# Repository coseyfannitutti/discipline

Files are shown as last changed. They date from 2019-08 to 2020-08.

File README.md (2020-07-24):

# DISCIPLINE V2

**65% keyboard assembled with only through hole components, including usb type-c**

**[LICENSE](LICENSE)**

Discipline V2 is licensed under the [Creative Commons Attribution-NonCommercial 4.0 International License](https://creativecommons.org/licenses/by-nc/4.0/). 

This PCB design may be freely reproduced, modified, and manufactured for **PERSONAL USE ONLY** and may not be reproduced in physical form for public sale outside of [CFTKB.com](https://www.cftkb.com). 

If you have built upon this work and have changed the design in a significant way, the non-commercial clause can be waived. If you have developed your own design using files in this repository and would like to sell it, please contact me at bryan@cftkb.com. I fully support those looking to make new things and be creative and will more than likely approve and support your project.

**[BOM, Build Guide, and Flashing Information](./doc)**

**Kits available at [cftkb.com](https://www.cftkb.com)**

**[Optional High Profile Lasercut Acrylic Case](./acrylic-case)**

discipline
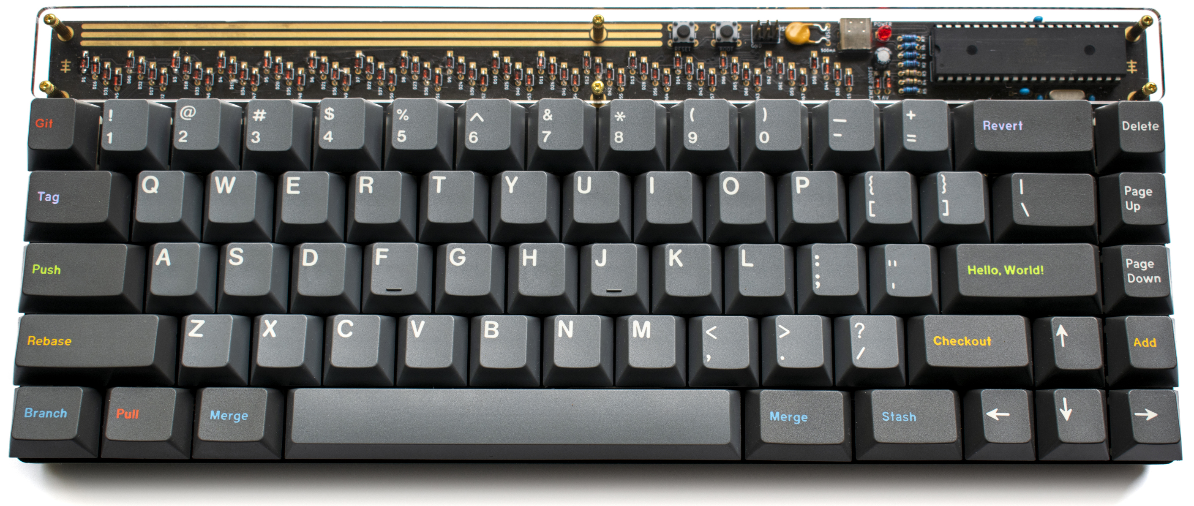
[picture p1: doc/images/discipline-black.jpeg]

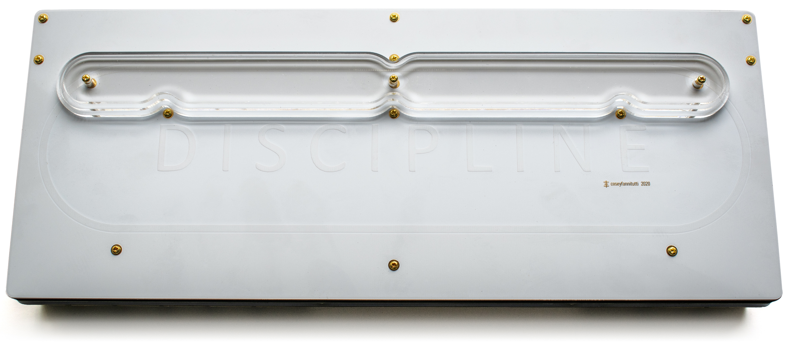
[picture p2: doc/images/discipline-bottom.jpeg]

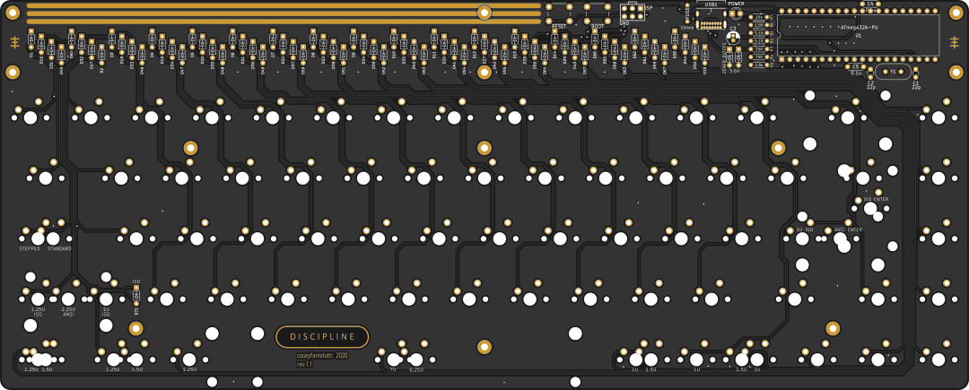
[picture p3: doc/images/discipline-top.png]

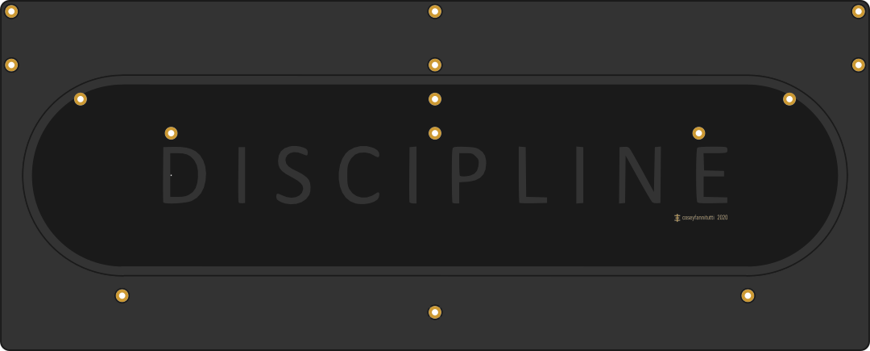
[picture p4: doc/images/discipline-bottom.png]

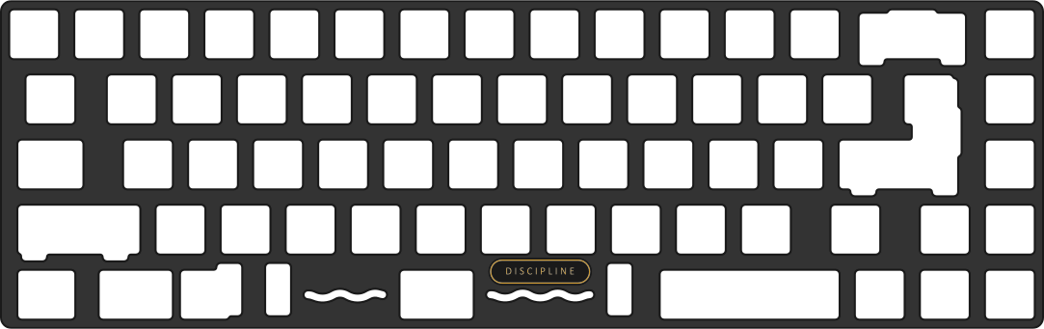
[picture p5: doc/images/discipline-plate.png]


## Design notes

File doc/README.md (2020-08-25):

# DISCIPLINE

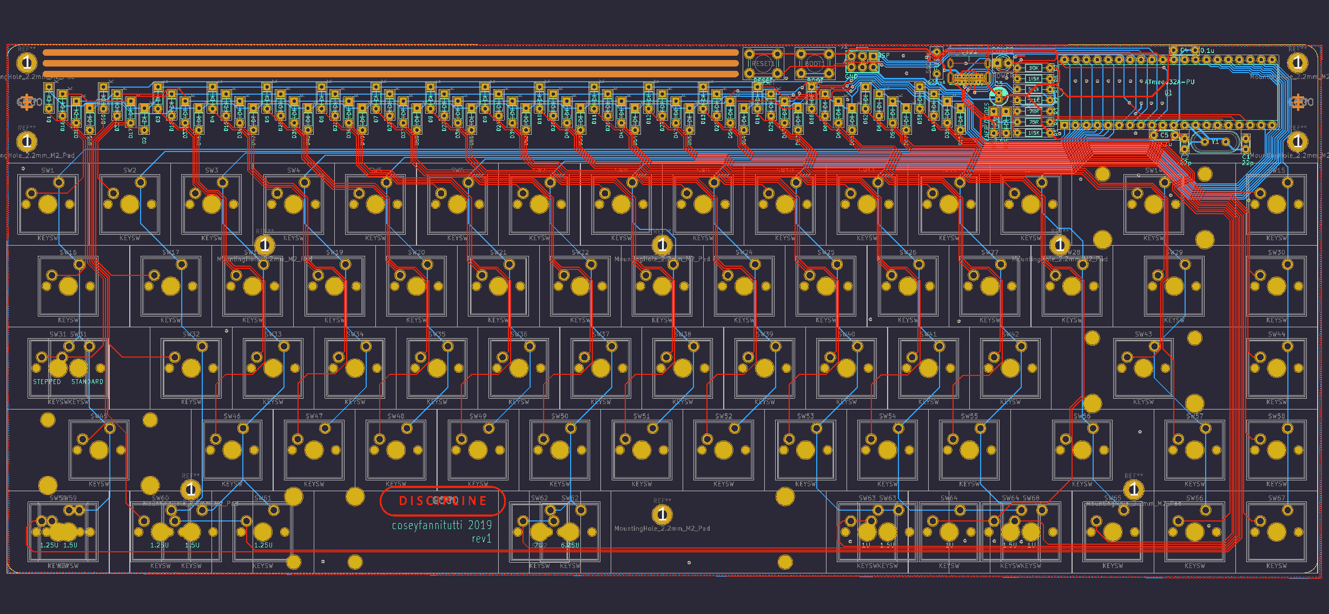
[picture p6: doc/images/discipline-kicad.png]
discipline


[Build Guide](https://www.cftkb.com/s/DISCIPLINE-BUILD-GUIDE.pdf)

[VIA Configurator Guide (Easiest)](https://static1.squarespace.com/static/5c533d33348cd92b886e544d/t/5e9fd1d198a4166c9ccc5b68/1587532241535/DISCIPLINE+VIA+GUIDE.pdf)

[QMK Toolbox Flashing Guide (not needed if using VIA)](https://static1.squarespace.com/static/5c533d33348cd92b886e544d/t/5e9fd3311e3c4e5bc9f8eb21/1587532594225/DISCIPLINE+FLASHING+GUIDE.pdf)

[Command Line Flashing Guide (Advanced)](https://static1.squarespace.com/static/5c533d33348cd92b886e544d/t/5e9fd3567e131c476b0a4f7e/1587532631133/DISCIPLINE+FLASHING+GUIDE+-+COMMAND+LINE.pdf)

[Bootloader](./bootloader)

[BOM (Parts List)](https://octopart.com/bom-tool/W4rybyut)

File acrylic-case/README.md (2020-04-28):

# Lasercut Acrylic Case with POM Plate

***This is case is OPTIONAL and not required. The kit has everything you need for a fully functional keyboard.
This case uses a different plate and is NOT compatible with the plate included in the kit.
If you have already soldered switches, you will need to desolder them and swap the plate.***

***I recommend using [Ponoko](https://www.ponoko.com) to cut the pieces. They have all of the correct/required thicknesses and materials in stock and have the best pricing that I have found for multiple one-off parts. Use clear acrylic for the full range of thickness options and Delrin (POM) for the plate. For proper fit please ensure you use the correct dimensions and material thicknesses noted below. Other colors may be used, but of the colors may have limited thickness options, so you may have to narrow material results by thickness to see which colors are available for that size.***

***Ponoko's automatic size detection when uploading is not flawless, so be sure to manually enter the dimensions below.***

## Part Dimensions/Thickness (Top to Bottom)
1. discipline-top-1.dxf - 320.9 x 138.8 mm - ***2mm thickness CLEAR ACRYLIC***
2. discipline-top-2.dxf ***x2 needed*** - 320.9 x 138.8 mm - ***3mm***
3. discipline-plate.dxf - 320.9 x 138.8 mm - ***1.5mm thickness DELRIN(POM)*** Can be black or white.
4. discipline-open-layer.dxf - 320.9 x 138.8 mm - ***4.5mm thickness***
5. discipline-closed-layer.dxf - 320.9 x 138.8 mm - ***3mm thickness***
6. discipline-bottom.dxf - 320.9 x 138.8 - ***3mm thickness*** Use matte (frosted) or colored acrylic if you don't want to clean up the flux on the bottom of your PCB.
7. discipline-foot-1.dxf - 276.5 x 28mm - ***3mm thickness***
8. discipline-foot-2.dxf - 272.5 x 24mm - ***3mm thickness***
9. discipline-foot-3.dxf - 268.5 x 20mm - ***3mm thickness***

## Screws and Standoffs
1. [30x m2x5mm screws](https://www.aliexpress.com/item/32870342767.html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,searchweb201602_7,searchweb201603_53)
2. [12x m2x14mm standoffs](https://www.aliexpress.com/item/32968906213.html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,searchweb201602_7,searchweb201603_53)
3. [3x m2x5mm standoffs](https://www.aliexpress.com/item/32968906213.html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,searchweb201602_7,searchweb201603_53)

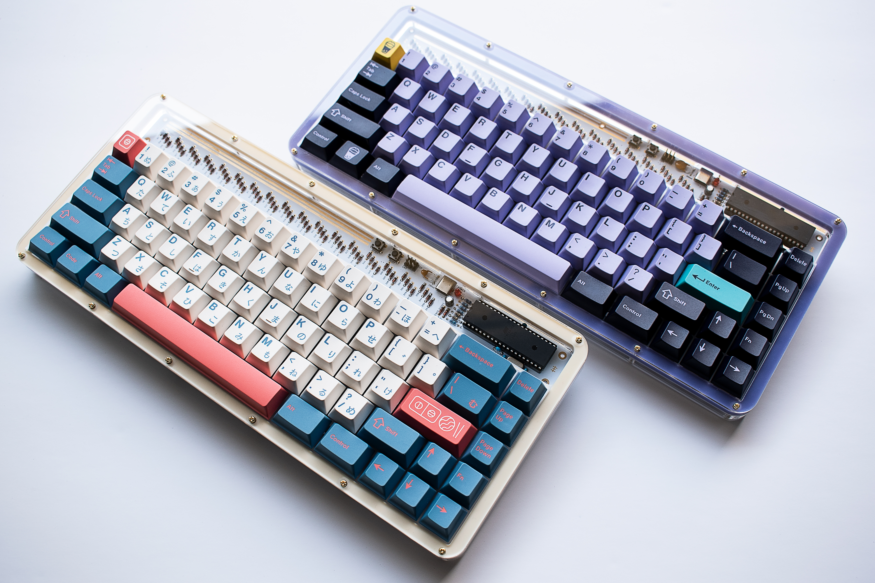
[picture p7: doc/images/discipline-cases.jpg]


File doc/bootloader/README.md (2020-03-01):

# Bootloader

## If you buy a kit from cftkb.com your microcontroller already has the bootloader flashed and you do not need this.

This project uses USBaspLoader as the usb bootloader on the atmega32a.
- My custom bootloader:   
https://github.com/coseyfannitutti/USBaspLoader/tree/atmega32a
  - Please ensure you are in the atmega32a branch of my fork of the USBaspLoader repository when downloading.
  - Follow the directions in the readme for directions on setting up the build environment for your operating system as well as flash instructions.
  - Makefile.inc sets flashing device as usbtiny, as I use a sparkfun pocket avr programmer. If you need to use another programmer please edit line 41 of Makefile.inc accordingly. Only edit Makefile.inc, and NEVER directly edit the actual Makefile.
  - Commands for flashing once build environment is set up:
  
	```make flash``` (flashes makefile)
  
  	```make fuse``` (sets fuses for microcontroller)
  
## Enter bootloader mode
1. Press and hold ```BOOT``` switch
2. Tap ```RESET``` switch
3. Release ```BOOT``` switch

Alternatively, you can hold ```BOOT``` switch while inserting the USB cable.

If you have successfully entered bootloader mode you should see USBaspLoader in device manager or as a connected device in QMK Toolbox.

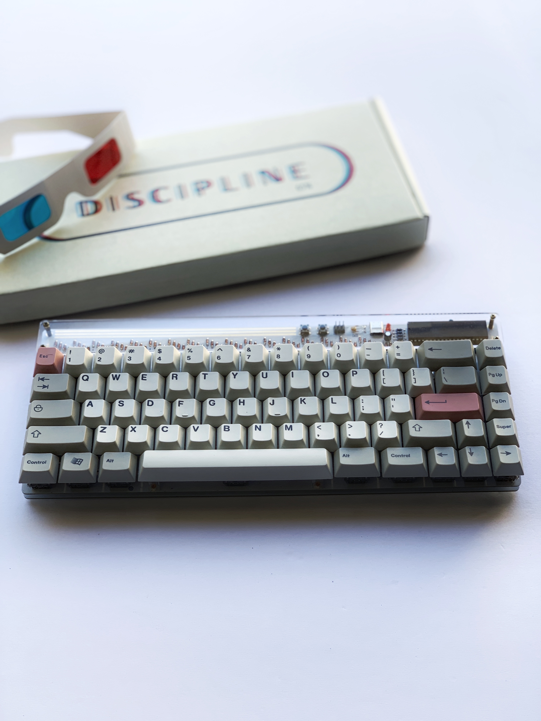
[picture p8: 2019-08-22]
doc/images/discipline-productpage.jpeg

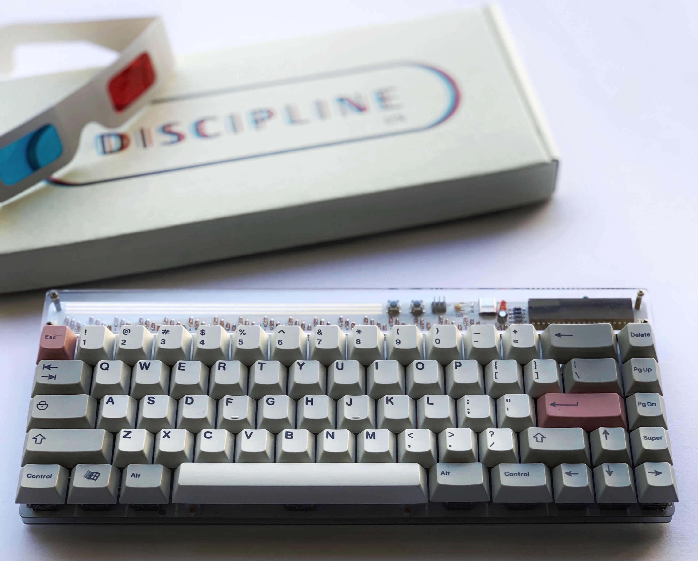
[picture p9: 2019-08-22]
doc/images/discipline-productpage-crop.jpeg

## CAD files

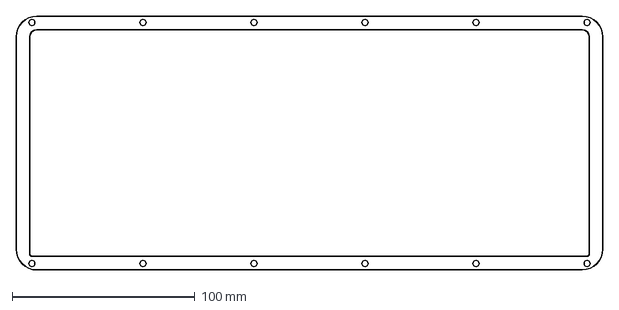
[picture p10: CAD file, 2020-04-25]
acrylic-case/discipline-top2.dxf
320.9 x 138.8 mm

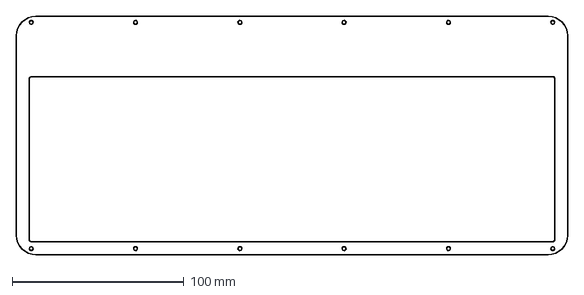
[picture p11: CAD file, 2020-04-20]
case/discipline-top-1.dxf
320.9 x 138.8 mm

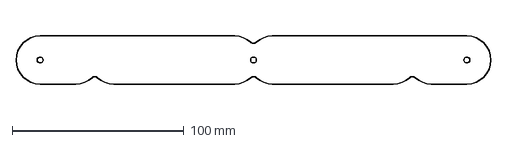
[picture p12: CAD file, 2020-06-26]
kit-acrylic/discipline-kitfoot-1.dxf
276.5 x 28.0 mm

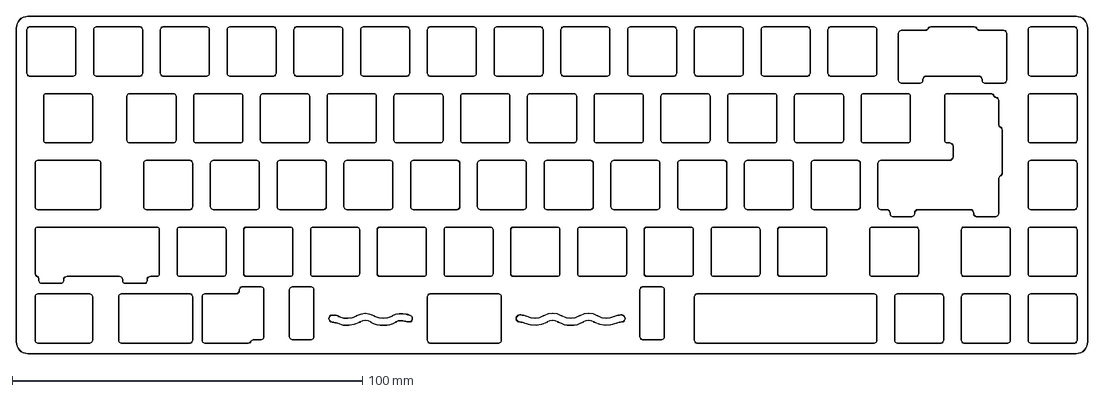
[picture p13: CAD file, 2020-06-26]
plate/discipline-plate-lasercutting.dxf
305.8 x 96.2 mm

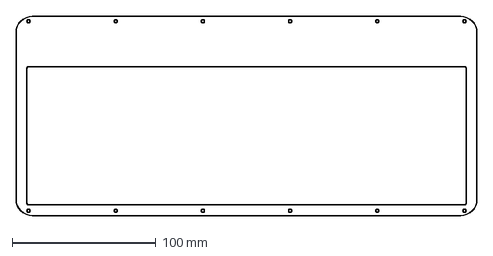
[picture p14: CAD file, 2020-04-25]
acrylic-case/discipline-top1.dxf
320.9 x 138.8 mm

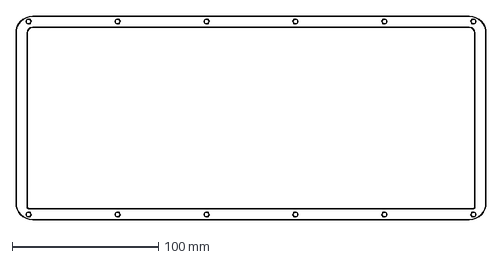
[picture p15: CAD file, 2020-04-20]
case/discipline-top-2.dxf
320.9 x 138.8 mm

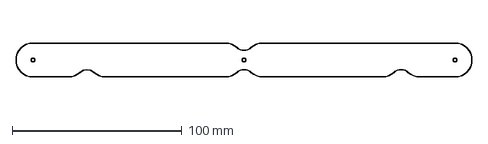
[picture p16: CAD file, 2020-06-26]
kit-acrylic/discipline-kitfoot-3.dxf
268.5 x 20.0 mm

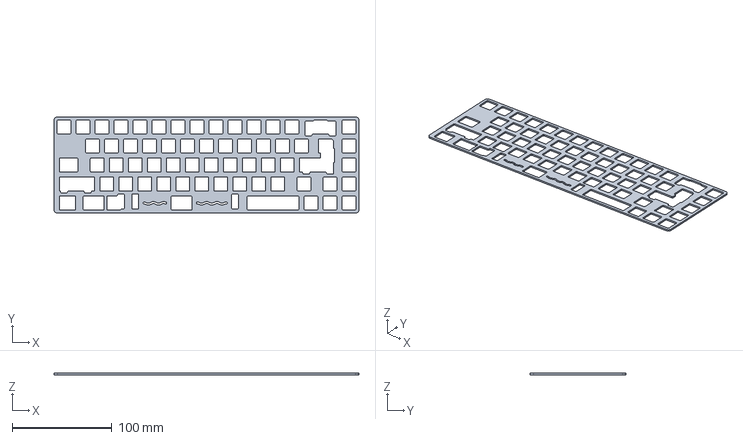
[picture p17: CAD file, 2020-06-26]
plate/discipline-pcb.step
305.8 x 96.2 x 1.60 mm

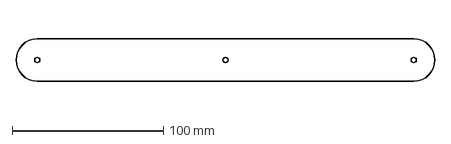
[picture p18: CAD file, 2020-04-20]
acrylic-case/discipline-foot-1.dxf
276.5 x 28.0 mm

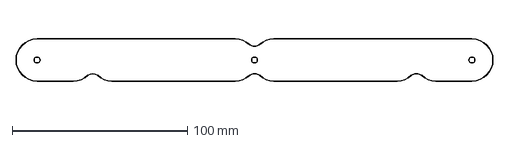
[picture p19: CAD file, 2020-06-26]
kit-acrylic/discipline-kitfoot-2.dxf
272.5 x 24.0 mm

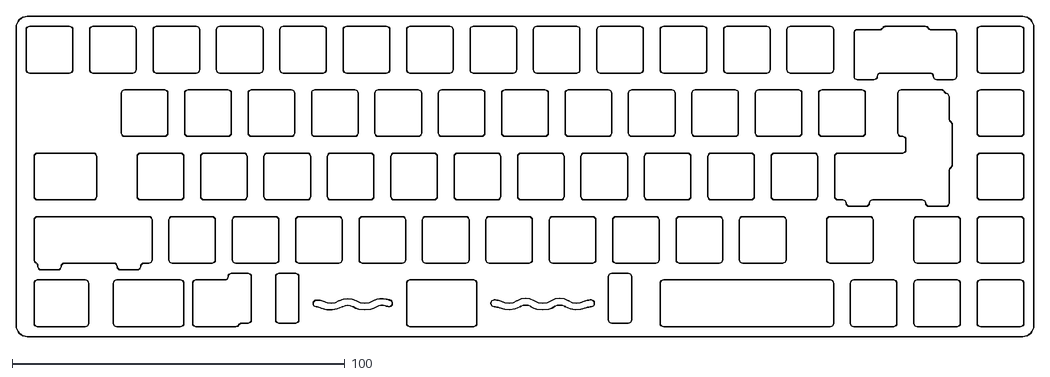
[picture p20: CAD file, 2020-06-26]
plate/discipline-plate-test.dxf
305.8 x 96.2

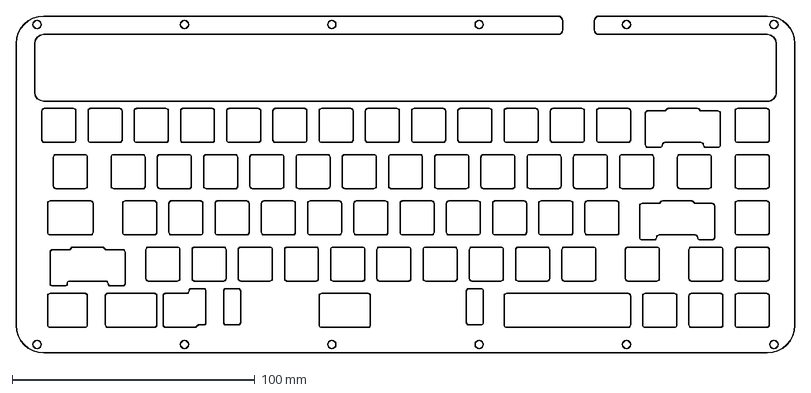
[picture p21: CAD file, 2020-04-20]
acrylic-case/discipline-plate.dxf
320.9 x 138.8 mm

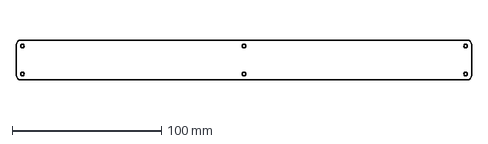
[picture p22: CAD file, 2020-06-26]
kit-acrylic/acrylic-guard.dxf
304.9 x 26.8 mm

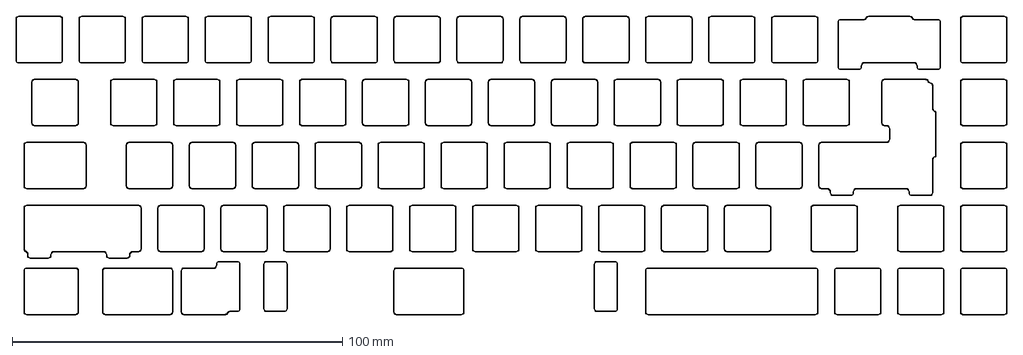
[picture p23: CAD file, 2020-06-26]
plate/discipline-plate-base.dxf
299.8 x 90.2 mm

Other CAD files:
acrylic-case/discipline-foot-3.dxf
acrylic-case/discipline-bottom.dxf
acrylic-case/discipline-open-layer.dxf
acrylic-case/discipline-closed-layer.dxf
acrylic-case/discipline-foot-2.dxf

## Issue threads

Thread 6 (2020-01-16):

Flashing bootloader with 6 pin IVR ASP programmer

liampelletier11, 2020-01-16:
I recently received the parts to assemble this keyboard but it wasn't as a kit, so I have to load the boot loader manually. I'm having trouble doing so even with the instructions and was hoping to get some help. I am running Windows 10 and the programmer I am using is linked below.

https://www.amazon.ca/USBtinyISP-Programmer-Bootloader-Download-Interface/dp/B07GYGC4NJ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

coseyfannitutti, 2020-01-16:
Have you installed WinAVR?

Building on Windows:
You need WinAVR for the firmware, see http://winavr.sourceforge.net/.
To build the firmware with WinAVR, change into the "USBaspLoader" directory,
check whether you need to edit the files mentioned above (e.g. change device
settings, programmer hardware, clock rate etc.) and type "make" to compile
the complete source code.
After you upload the code to the device with "make flash", you should set
the fuses with "make fuse".

liampelletier11, 2020-01-16:
I have WinAVR and I'm assuming I build it from the command prompt, but whenever I use the make command I get error messages.
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

coseyfannitutti, 2020-01-16:
Just go ahead and run make flash and make fuse. Make is only really necessary if you need to change anything. Doesn't hurt anything to run it, but you'll get the errors you see there if nothing has changed since the last compile.

liampelletier11, 2020-01-16:
Now I get an error saying that it could not find USBtiny device

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

coseyfannitutti, 2020-01-16:
Not sure. That's an issue with your ISP programmer and Windows not detecting it. Perhaps a driver needs to be installed. Is it showing up in device manager? I've used the sparkfun pocket avr programmer (also a usbtiny device) as well as usbasp with this bootloader, and they required nothing more than installing WinAVR and running the commands.

Install zadig at https://zadig.akeo.ie/

Run. Click Options > List all devices.
Select your programmer from the drop down menu.
What driver is installed?

liampelletier11, 2020-01-16:
The driver that is installed is libusb0

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

coseyfannitutti, 2020-01-16:
You can try replacing it with libusb-win32.
Otherwise, I'm not sure what to tell you. Possibly a faulty device.
Maybe a restart is necessary after installing WinAVR.

If that still doesn't work I would recommend trying a USBasp instead. They are inexpensive.

If you decide to try a USBasp instead, a very simple change would need to be made to lines 40 and 41 in the Makefile.inc file.

1. Remove the hash at the beginning of the line "PROGRAMMER = -c usbasp"
2. Add a hash at the beginning of the line "# PROGRAMMER = -c usbtiny"

liampelletier11, 2020-01-16:
I was looking at other solutions and would it be possible to use an arduino uno to attempt and flash the atmega32a instead of the programmer directly?

coseyfannitutti, 2020-01-17:
I can really only speak to the functionality of the two programmers I’ve personally used, which are USBasp and Sparkfun Pocket AVR Programmer.

liampelletier11, 2020-01-17:
Ok so I tried some new things and now I get a new error with make flash and make fuse. Also, am I supposed to have the usb-c cable attached when I run the make commands?

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

coseyfannitutti, 2020-01-17:
If the power indicator led turns on when connected to the programmer than no you do should not have the usb cable plugged in. Are you sure that your microcontroller is in the correct orientation (notch to the left)?

jrgaitan, 2020-01-17:
Hi, I am having a similar issue, I'm using an USBasp, already changed the makefile.inc but in the following error shows up when I use the make and make flash command.
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

coseyfannitutti, 2020-01-17:
Ah okay I know this problem.

Download this file: http://www.madwizard.org/download/electronics/msys-1.0-vista64.zip
Unzip it and copy msys-1.0.dll to the \utils\bin directory of your WinAVR folder.

You may need to restart your computer.

jrgaitan, 2020-01-17:
It worked, thank you very much.

coseyfannitutti, 2020-01-17:
Glad you got it working.

liampelletier11, 2020-01-18:
I have the microcontroller in the correct orientation

coseyfannitutti, 2020-01-18:
Another thing to check is the orientation of your 6-pin cable on the header of the pcb. Make sure the notch [as seen in this picture](https://cdn.sparkfun.com/assets/learn_tutorials/2/9/2/2x3-labeled.jpg) is in the same orientation as the silkscreen on the pcb, notch pointing upward.

In the last screenshot you sent, your computer has recognized the programmer, but it is not communicating with the microcontroller. I can see WinAVR is installed, and you are entering the correct commands.

If you are certain that your pcb doesn't have any shorts, the microcontroller is in the correct orientation, and the cable is connected correctly to the 6-pin header, the issue most likely lies with the isp programmer or the 6-pin cable. The only advice I can give for that is to use one of the two programmers that I have previously suggested. I can't recommend using any others because I have not personally tried them.

Julian4314, 2020-01-18:
I need to chip in on this conversation, because i am running into the exact same problem liampelletier11 has.
I am using an USBasp, changed the right parts of the makefile but can´t seem to connect to the board. But i was able to flash a qmk hex file onto an atmega328p with a basic bootloader using the same setup, so all connections seem to be working just fine.
It´s just that i can´t seemt to find a way to either flash the discipad or discipline board i have here.

coseyfannitutti, 2020-01-18:
I would double check everywhere on the board for shorts. There must be a physical issue causing that. Someone else in the conversation using a USBasp flashed the bootloader just fine. Works for me as well.

Julian4314, 2020-01-18:
It´s working now, but for what ever reason i had to flash another bootloader first before i was able to use the USBasp to flash your USBaspLoader.

coseyfannitutti, 2020-01-18:
That is bizarre. There shouldn’t be anything on a blank ATmega32A that would prevent it from being flashed with this bootloader.

liampelletier11, 2020-01-21:
If there were any shorts on the PCB that would be causing this error, which connectors would most likely be shorted? I'm pretty sure that all of my joints are ok but I have attached a picture as well just in case.

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

coseyfannitutti, 2020-01-21:
The USB port is generally the most likely spot, but yours looks pretty good.
Does the power indicator turn on when you connect the ISP programmer (USB not connected)?

liampelletier11, 2020-01-21:
The power LED does turn on with the ISP connected

coseyfannitutti, 2020-01-21:
My apologies, but I've really got nothing else then. This is not an issue with the bootloader. If everything else has been done properly, it's either the ISP programmer or the cable going from the programmer to the header on the board.

liampelletier11, 2020-01-22:
That's ok, thank you very much for your help! I've ordered a USBasp to try and see if that fixes the issue

liampelletier11, 2020-01-22:
Turns out it was the programmer not working, had no problems at all with the USBasp. Thanks once again for your help!

coseyfannitutti, 2020-01-23:
No problem at all. Glad to hear you got it worked out.

quantd55, 2020-03-16:
Does this programmer can flash bootloader for atmega32a? ty.
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

coseyfannitutti, 2020-03-16:
@quantd55 I have only personally used Sparkfun Pocket AVR Programmer and USBasp (with 10-pin to 6-pin adapter) with this repository. I'm sure there are others that may work, but I have not tested them. I cannot say with certainty which programmers will work outside of the two recommended above.

quantd55, 2020-03-17:
> USBasp

Ty, I will change to the USBasp.

Closed 2020-01-23.

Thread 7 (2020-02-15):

dxf file size when uploaded to ponoko

Ashtoruin, 2020-02-15:
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

I was looking to do a run myself for me and a friend in the UK and figured I'd start by looking at Ponoko (since you suggested it for the cases) but when I upload the file for the discipline guard (I checked the Mysterium Guard + Nav also) I noticed that the sizes are way off. I'm assuming they're just scaled wrong and I need to manually override the size but you don't actually list what the sizes should be. I can probably figure it out myself but it would be nice if we had some values to sanity check against.

Judging from the size of the boards:
Discipline Guard: 304.9W?
Mysterium Guard: 347.7W?
Mysterium Nav: ?

coseyfannitutti, 2020-02-18:
Manually entering 304.9 x 26.8 will get you the correct results.

There just seems to be issues with Ponoko's new auto detection system they recently launched.
The files were designed in mm and when measured in AutoCAD they show the correct size, and I'm not sure what would cause a scaling of one third, as mm to in would be either .04x or 25.4x.

Rest assured, though, if you manually enter those dimensions it will come out correct. I have be using them for a long time over several projects, and have never received an incorrectly sized piece.

Uploading it to other services shows it scaling correctly.
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

Ashtoruin, 2020-02-18:
Yeah, I actually opened them up in Fusion and double checked my sizes but I figured it might be nice to document this in the Readme or something for people wanting to print their own that aren't as familiar with CADD programs and such.

coseyfannitutti, 2020-02-18:
I agree. I want to keep the main page as simple as possible, but I have added a note about manual dimension entry for Ponoko in the Readme for the case folders of Discipline and Mysterium.

Closed 2020-02-19.

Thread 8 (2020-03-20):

Version with split backspace?

ElectricCoffee, 2020-03-20:
Hi, love the design, I'm just wondering if you could also make a version of the PCB that has a split backspace?

That might sound strange at first, but it frees up room for the <code>`~</code> key, so it doesn't have to share space with <code>Esc</code>.

For an example of this in action, see the Sun Model 7:

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

lstubbig, 2020-04-07:
A similar suggestion: I would love to see a version with split spacebars (2.75u 1.25u 2.25u). It's something really useful that practically no off-the-shelf keyboards offer. Would fit really well to the DIY character of the board and make it a definite buy for me.

ElectricCoffee, 2020-04-07:
@lstubbig totally agree, a split spacebar would be neat for enabling an easy-to-reach extra custom bindable key. Though I fear finding half spacebars might be hard...

lstubbig, 2020-04-07:
@ElectricCoffee Most keycap sets have an option for small spacebars nowadays (at least GMK and MT3 from Drop). You can also get relatively cheap XDA keycaps from Aliexpress.
@coseyfannitutti Would you be open to this? I don't have experience with KiCAD but if you give us some pointers maybe we can even add those features ourselves?

ElectricCoffee, 2020-04-10:
@lstubbig for the spit spacebar I'd instead have it split into four 1.5u keys or maybe three 2u keys.
Something about the Romeo's wide-narrow-wide spacebar cluster looks wrong to me...

mobin-amanzai, 2020-04-29:
@ElectricCoffee you could make a comprise sand share the left shift with the`~`` key

savyexe, 2020-07-30:
> @ElectricCoffee Most keycap sets have an option for small spacebars nowadays (at least GMK and MT3 from Drop). You can also get relatively cheap XDA keycaps from Aliexpress.
> @coseyfannitutti Would you be open to this? I don't have experience with KiCAD but if you give us some pointers maybe we can even add those features ourselves?

hey, i know it's been months since you guys talked about this but i wanted to say that if you do end up doing a 2.75u 1.25u 2.25u split spacebar version and @coseyfannitutti gives you permission to place it as a sort of groupbuy i'd be interested

Closed 2020-08-25.

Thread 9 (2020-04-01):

How to setup RGB Underglow?

sendz, 2020-04-01:
So I tried to solder some WS2812B RGB strip and connected +5v and GND directly to USB pin, and for the RGB data in, I soldered to pin number `33` which is `A7` pin, however after enable the `RGBLIGHT_ENABLE` on `rules.mk`,  setup the RGB pin as well in `config.h`, and add some hotkeys to activate RGB mode, it doesn't works.

my `config.h`
```
/*Copyright 2019 coseyfannitutti

This program is free software: you can redistribute it and/or modify
it under the terms of the GNU General Public License as published by
the Free Software Foundation, either version 2 of the License, or
(at your option) any later version.

This program is distributed in the hope that it will be useful,
but WITHOUT ANY WARRANTY; without even the implied warranty of
MERCHANTABILITY or FITNESS FOR A PARTICULAR PURPOSE.  See the
GNU General Public License for more details.

You should have received a copy of the GNU General Public License
along with this program.  If not, see <http://www.gnu.org/licenses/>.
*/

#pragma once

#include "config_common.h"

#define VENDOR_ID       0xFEED
#define PRODUCT_ID      0x6869
#define DEVICE_VER      0x0001
#define MANUFACTURER    coseyfannitutti
#define PRODUCT         DISCIPLINE
#define DESCRIPTION     65% keyboard that can be assembled with only through hole components

/* key matrix size */
#define MATRIX_ROWS 5
#define MATRIX_COLS 15

/*
 * Keyboard Matrix Assignments
 *
 * Change this to how you wired your keyboard
 * COLS: AVR pins used for columns, left to right
 * ROWS: AVR pins used for rows, top to bottom
 * DIODE_DIRECTION: COL2ROW = COL = Anode (+), ROW = Cathode (-, marked on diode)
 *                  ROW2COL = ROW = Anode (+), COL = Cathode (-, marked on diode)
 *
 */

#define MATRIX_ROW_PINS { B2, A1, B1, A0, B0 }
#define MATRIX_COL_PINS { A2, B3, A3, B4, A4, D5, D6, C6, C5, C4, C3, C2, C1, C0, D7 }
#define UNUSED_PINS

/* COL2ROW, ROW2COL*/
#define DIODE_DIRECTION COL2ROW

#define USB_MAX_POWER_CONSUMPTION 100

/*
 * Split Keyboard specific options, make sure you have 'SPLIT_KEYBOARD = yes' in your rules.mk, and define SOFT_SERIAL_PIN.
 */
// #define SOFT_SERIAL_PIN D0 // or D1, D2, D3, E6

// #define BACKLIGHT_PIN B7
// #define BACKLIGHT_BREATHING
// #define BACKLIGHT_LEVELS 3

#define RGB_DI_PIN A7
#ifdef RGB_DI_PIN
  #define RGBLED_NUM 16
  #define RGBLIGHT_HUE_STEP 8
  #define RGBLIGHT_SAT_STEP 8
  #define RGBLIGHT_VAL_STEP 8
  #define RGBLIGHT_LIMIT_VAL 255 /* The maximum brightness level */
  #define RGBLIGHT_SLEEP  /* If defined, the RGB lighting will be switched off when the host goes to sleep */
/*== all animations enable ==*/
  #define RGBLIGHT_ANIMATIONS
/*== or choose animations ==*/
  #define RGBLIGHT_EFFECT_BREATHING
  #define RGBLIGHT_EFFECT_RAINBOW_MOOD
  #define RGBLIGHT_EFFECT_RAINBOW_SWIRL
  #define RGBLIGHT_EFFECT_SNAKE
  #define RGBLIGHT_EFFECT_KNIGHT
  #define RGBLIGHT_EFFECT_CHRISTMAS
  #define RGBLIGHT_EFFECT_STATIC_GRADIENT
  #define RGBLIGHT_EFFECT_RGB_TEST
  #define RGBLIGHT_EFFECT_ALTERNATING
#endif

/* Debounce reduces chatter (unintended double-presses) - set 0 if debouncing is not needed */
#define DEBOUNCE 5

/* define if matrix has ghost (lacks anti-ghosting diodes) */
//#define MATRIX_HAS_GHOST

/* number of backlight levels */

/* Mechanical locking support. Use KC_LCAP, KC_LNUM or KC_LSCR instead in keymap */
#define LOCKING_SUPPORT_ENABLE
/* Locking resynchronize hack */
#define LOCKING_RESYNC_ENABLE

/* If defined, GRAVE_ESC will always act as ESC when CTRL is held.
 * This is userful for the Windows task manager shortcut (ctrl+shift+esc).
 */
// #define GRAVE_ESC_CTRL_OVERRIDE

/*
 * Force NKRO
 *
 * Force NKRO (nKey Rollover) to be enabled by default, regardless of the saved
 * state in the bootmagic EEPROM settings. (Note that NKRO must be enabled in the
 * makefile for this to work.)
 *
 * If forced on, NKRO can be disabled via magic key (default = LShift+RShift+N)
 * until the next keyboard reset.
 *
 * NKRO may prevent your keystrokes from being detected in the BIOS, but it is
 * fully operational during normal computer usage.
 *
 * For a less heavy-handed approach, enable NKRO via magic key (LShift+RShift+N)
 * or via bootmagic (hold SPACE+N while plugging in the keyboard). Once set by
 * bootmagic, NKRO mode will always be enabled until it is toggled again during a
 * power-up.
 *
 */
//#define FORCE_NKRO

/*
 * Magic Key Options
 *
 * Magic keys are hotkey commands that allow control over firmware functions of
 * the keyboard. They are best used in combination with the HID Listen program,
 * found here: https://www.pjrc.com/teensy/hid_listen.html
 *
 * The options below allow the magic key functionality to be changed. This is
 * useful if your keyboard/keypad is missing keys and you want magic key support.
 *
 */

/* key combination for magic key command */
/* defined by default; to change, uncomment and set to the combination you want */
// #define IS_COMMAND() (get_mods() == (MOD_BIT(KC_LSHIFT) | MOD_BIT(KC_RSHIFT)))

/* control how magic key switches layers */
//#define MAGIC_KEY_SWITCH_LAYER_WITH_FKEYS  true
//#define MAGIC_KEY_SWITCH_LAYER_WITH_NKEYS  true
//#define MAGIC_KEY_SWITCH_LAYER_WITH_CUSTOM false

/* override magic key keymap */
//#define MAGIC_KEY_SWITCH_LAYER_WITH_FKEYS
//#define MAGIC_KEY_SWITCH_LAYER_WITH_NKEYS
//#define MAGIC_KEY_SWITCH_LAYER_WITH_CUSTOM
//#define MAGIC_KEY_HELP           H
//#define MAGIC_KEY_HELP_ALT       SLASH
//#define MAGIC_KEY_DEBUG          D
//#define MAGIC_KEY_DEBUG_MATRIX   X
//#define MAGIC_KEY_DEBUG_KBD      K
//#define MAGIC_KEY_DEBUG_MOUSE    M
//#define MAGIC_KEY_VERSION        V
//#define MAGIC_KEY_STATUS         S
//#define MAGIC_KEY_CONSOLE        C
//#define MAGIC_KEY_LAYER0         0
//#define MAGIC_KEY_LAYER0_ALT     GRAVE
//#define MAGIC_KEY_LAYER1         1
//#define MAGIC_KEY_LAYER2         2
//#define MAGIC_KEY_LAYER3         3
//#define MAGIC_KEY_LAYER4         4
//#define MAGIC_KEY_LAYER5         5
//#define MAGIC_KEY_LAYER6         6
//#define MAGIC_KEY_LAYER7         7
//#define MAGIC_KEY_LAYER8         8
//#define MAGIC_KEY_LAYER9         9
//#define MAGIC_KEY_BOOTLOADER     B
//#define MAGIC_KEY_BOOTLOADER_ALT ESC
//#define MAGIC_KEY_LOCK           CAPS
//#define MAGIC_KEY_EEPROM         E
//#define MAGIC_KEY_EEPROM_CLEAR   BSPACE
//#define MAGIC_KEY_NKRO           N
//#define MAGIC_KEY_SLEEP_LED      Z

/*
 * Feature disable options
 *  These options are also useful to firmware size reduction.
 */

/* disable debug print */
//#define NO_DEBUG

/* disable print */
//#define NO_PRINT

/* disable action features */
//#define NO_ACTION_LAYER
//#define NO_ACTION_TAPPING
//#define NO_ACTION_ONESHOT
//#define NO_ACTION_MACRO
//#define NO_ACTION_FUNCTION

/*
 * MIDI options
 */

/* Prevent use of disabled MIDI features in the keymap */
//#define MIDI_ENABLE_STRICT 1

/* enable basic MIDI features:
   - MIDI notes can be sent when in Music mode is on
*/
//#define MIDI_BASIC

/* enable advanced MIDI features:
   - MIDI notes can be added to the keymap
   - Octave shift and transpose
   - Virtual sustain, portamento, and modulation wheel
   - etc.
*/
//#define MIDI_ADVANCED

/* override number of MIDI tone keycodes (each octave adds 12 keycodes and allocates 12 bytes) */
//#define MIDI_TONE_KEYCODE_OCTAVES 1

/*
 * HD44780 LCD Display Configuration
 */
/*
#define LCD_LINES           2     //< number of visible lines of the display
#define LCD_DISP_LENGTH    16     //< visibles characters per line of the display

#define LCD_IO_MODE      1            //< 0: memory mapped mode, 1: IO port mode

#if LCD_IO_MODE
#define LCD_PORT         PORTB        //< port for the LCD lines
#define LCD_DATA0_PORT   LCD_PORT     //< port for 4bit data bit 0
#define LCD_DATA1_PORT   LCD_PORT     //< port for 4bit data bit 1
#define LCD_DATA2_PORT   LCD_PORT     //< port for 4bit data bit 2
#define LCD_DATA3_PORT   LCD_PORT     //< port for 4bit data bit 3
#define LCD_DATA0_PIN    4            //< pin for 4bit data bit 0
#define LCD_DATA1_PIN    5            //< pin for 4bit data bit 1
#define LCD_DATA2_PIN    6            //< pin for 4bit data bit 2
#define LCD_DATA3_PIN    7            //< pin for 4bit data bit 3
#define LCD_RS_PORT      LCD_PORT     //< port for RS line
#define LCD_RS_PIN       3            //< pin  for RS line
#define LCD_RW_PORT      LCD_PORT     //< port for RW line
#define LCD_RW_PIN       2            //< pin  for RW line
#define LCD_E_PORT       LCD_PORT     //< port for Enable line
#define LCD_E_PIN        1            //< pin  for Enable line
#endif
*/

/* Bootmagic Lite key configuration */
#define BOOTMAGIC_LITE_ROW 0
#define BOOTMAGIC_LITE_COLUMN 0
```

my `rules.mk`
```
# MCU name
MCU = atmega32a

# Processor frequency
F_CPU = 16000000

# Bootloader selection
#   Teensy       halfkay
#   Pro Micro    caterina
#   Atmel DFU    atmel-dfu
#   LUFA DFU     lufa-dfu
#   QMK DFU      qmk-dfu
#   ATmega32A    bootloadHID
#   ATmega328P   USBasp
BOOTLOADER = USBasp

# disable debug code
OPT_DEFS = -DDEBUG_LEVEL=0

# Build Options
#   change yes to no to disable
#
BOOTMAGIC_ENABLE = no      # Virtual DIP switch configuration
MOUSEKEY_ENABLE = yes       # Mouse keys
EXTRAKEY_ENABLE = yes       # Audio control and System control
CONSOLE_ENABLE = no        # Console for debug
COMMAND_ENABLE = no        # Commands for debug and configuration
# Do not enable SLEEP_LED_ENABLE. it uses the same timer as BACKLIGHT_ENABLE
SLEEP_LED_ENABLE = no       # Breathing sleep LED during USB suspend
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
darthandre, 2020-05-17:
Try changing the power consumption level to 250 or 300

#define USB_MAX_POWER_CONSUMPTION 100 > #define USB_MAX_POWER_CONSUMPTION 250
In your config.h

Everything looks ok, I have wired my A6 pin as data in for the neopixel led's and worked fine.

Just try changing that on your config.h, good luck man!

sendz, 2020-06-05:
thanks @darthandre , seems works now, appreciate it!

sirleo08, 2022-07-23:
can i get the hex file please

Closed 2020-06-05.

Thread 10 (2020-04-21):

discipline-top-2.dxf file

cesaremiliodo, 2020-04-21:
Hey,

The new discipline-top-2.dxf file doesn't work on Ponoko. I try to upload it and the webpage crash.

ninizheng18, 2020-04-24:
I'm having the same problem with both of the top.dxf files. They either crash the page or they don't like to be uploaded at all.

discipline-top-1.dxf
discipline-top-2.dxf

Not sure if this is an issue with the files or Ponoko?

coseyfannitutti, 2020-04-25:
Well, I have sort of a bizarre solution for you guys. The filename was actually the problem.

This is definitely an issue with Ponoko's system at the moment. I have previously used these files to have the case cut and have just looked them over extensively for any gaps and errors.

After seeing you guys saying this I tried and had the same issue.

I was able to get them to upload simply by removing the second dash from the filename, and they uploaded just fine for me now. Renaming them discipline-top1 and discipline-top2 was the only thing that changed.

No idea why having a second dash would now cause an issue when it previously didn't, but this should solve your issue. I have been able to upload it successfully several times.

ninizheng18, 2020-04-25:
It was still a little finicky even after I changed the names but it eventually worked. Thanks!

Is there any issue with using the "Clear impact modified acrylic" for the 2mm top piece instead of the regular clear acrylic? I figure, the more durable, the better.

coseyfannitutti, 2020-04-25:
@ninizheng18 No, you won’t have any problems with that at all. It’s just a little more expensive.

Closed 2020-04-25.

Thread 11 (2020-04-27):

Question about ISO support

ilyen85, 2020-04-27:
Hey Coseyfannitutti

First of all I would like to thank you for your fantastic work!

So my question, I missed the group buy on Friday, it was sold out when I managed to enter my details :( So I figured I will buy / create the necessary parts.

I have never did anything like this before so I have a couple of questions.
If I use a pcb manufacturing service, do I need anything else than the files in the gerber folder in this repo?

With these files will I be able to have an ISO compatible pcb?

Thank you again!

mozaic-dev, 2020-04-29:
@ilyen85 yeah, there is even a picture of the white PCB showing off ISO enter

coseyfannitutti, 2020-04-29:
Currently, no the ISO support and other changes for V2 are not yet in the repository. The version here only has ANSI compatibility.

I will be opening a larger pre-sale on Friday at 12PM US Eastern time to help meet some of the demand after they sold out so quickly last week.

I will be updating this repository with the ISO compatibility and other changes some time after that pre-sale has run.

ilyen85, 2020-04-30:
Thank you! I will wait for that, I hope i will be able to grab a kit (or two) :)

Since I know that ISO compatibility is not yet in the repo I will close this issue

Closed 2020-04-30.

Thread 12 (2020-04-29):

Discipline65 Case

jthoms1, 2020-04-29:
I was unsure about the colors you chose for the picture provided for the case.  It looks like you built those from Ponoko and used Lavender Acrylic and Cream Acrylic for the 2 x discpline-top2.

Is that correct? If so do you mind if I make a pull request to update your readme to give guidance to others looking to build those cases.

Oh those cases look amazing.

coseyfannitutti, 2020-06-04:
Yes, that is correct.

Closed 2020-06-04.

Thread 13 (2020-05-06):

Bluetooth for V3

louia, 2020-05-06:
is there any plans to add bluetooth and battery ?

coseyfannitutti, 2020-05-06:
Not at this time, no. That would require either using an expensive 32u4
Feather BLE from Sparkfun or adding smd parts that also need to be
programmed in such a way that would prevent this kit from being sold and
built as it is now.

The lack of extensive Bluetooth support with qmk and potential headaches
with connectivity limitations for users doesn't help. It's just not a
priority at the moment.

However, this design could be edited by someone looking for a project to
use something like the 32u4 Feather BLE from Sparkfun. That board will,
however have significantly less i/o pins and would require a port expander
and significant changes to the firmware. One of my other smaller boards
like the Romeo or Discipad could be adapted for use with the Feather
without using a port expander.

On Wed, May 6, 2020 at 10:33 AM Louis Chovaneck <notifications@github.com>
wrote:

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

louia, 2020-05-06:
Thanks for your explication and your response

louia, 2020-05-07:
After some search on the www, i discover [this project](https://github.com/Galzai/MK32) but it doesnt compatible with QMK and on reddit i found this reply if one day it may be usefull for you or for someone else : [reddit](https://www.reddit.com/r/MechanicalKeyboards/comments/9d6w1y/prototyping_boards_for_my_esp32_based_wireless/e5lqt2p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)

coseyfannitutti, 2020-05-08:
Maybe. We'll see how porting of new microcontrollers and alternate firmware options develop. If it is possible to keep the user experience as easy and friendly as QMK and VIA, then it may be something to consider.

Closed 2020-05-09.

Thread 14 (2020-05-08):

Kit Plate and Foam

goranzarkovic, 2020-05-08:

goranzarkovic, 2020-05-13:
resolved.

Elkasitu, 2020-06-20:
@goranzarkovic did you find the .dxf? I'm also looking for a backplate that I can print myself

jesusignazio, 2020-06-21:
@Elkasitu I think it is provided here https://github.com/coseyfannitutti/discipline/tree/master/case

Elkasitu, 2020-06-21:
@jesusignazio From checking the files, the bottom case model seems to be for the full-acrylic case and is at least 15mm taller than the PCB.

The kit backplate seems to be the same size, the holes align with the PCB plus comes with extra holes for feet, here's a pic
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

@coseyfannitutti is there any way you could share the file for the backplate included in the kit?

coseyfannitutti, 2020-06-21:
The bottom is already in the repository. In the gerber folder there are files for the bottom.

Elkasitu, 2020-06-22:
Damn thanks, don't know how I missed that

Closed 2020-05-13.

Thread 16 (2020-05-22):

LED backlit keys

darthrookie, 2020-05-22:
Is there a plan for a future version with LED backlit keys? That would be IMO all this keyboard is missing. If I find the time I could edit the schematic and perhaps the PCB routing, but since I am new with keyboards, that could take some time since I am not familiar with common components and pin outs for this application.

Also perhaps a version with a dedicated "~" key. For a solution right now I was thinking on moving the ESC key to where DEL is, assign DEL as a secondary function of BACK, and put ~ where ESC is.

dhanakane, 2020-09-17:
Most people will reassign ESC to CAPS LOCK.

SuperNici, 2021-05-08:
As @dhanakane mentioned this can be done in [VIA](https://caniusevia.com/)

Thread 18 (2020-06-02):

Plate layout?

andywarburton, 2020-06-02:
Hey. I'm self building the Discipline V2 board (because a) I'm impatient and b) I missed the groupbuys) and was wondering if you could please make the gerbers for the switch plate available? Cheers!

coseyfannitutti, 2020-06-02:
This repository is currently V1. It will be updated to V2 sometime after pre-orders have been fulfilled. Both versions of the board can be built plateless and will be functionally the same if using PCB mount (5-pin) switches.

andywarburton, 2020-06-02:
Ah cool. That makes things a little easier. I guess I'll just keep chugging away with my V1 build and build a V2 afterwards :)

andywarburton, 2020-06-02:
btw... thanks so much for being so open (source) with your designs. It's so refreshing to see someone just openly give away their designs for free like this. I promise I'll get in on a future groupbuy if our timelines ever cross :)

coseyfannitutti, 2020-06-03:
I did just remember that 65% tray mount style plates such as those that are sold by kbdfans and kprepublic are compatible with Discipline.

And no problem regarding the open sourcing. Customization and open source hardware were what got me into keyboards in the first place. Happy to contribute in the same manner and give people the satisfaction of building something from start to finish or provide a jumping off point to redesign for their own needs.

andywarburton, 2020-06-03:
Does this look like the right one? (it looks like they have it in carbon fiber and brass too)
https://www.aliexpress.com/item/32999460415.html

coseyfannitutti, 2020-06-03:
Yep! That should work just fine. I’ve seen several users build theirs with both carbon fiber and brass.

coseyfannitutti, 2020-06-03:
Just make sure when building to attach screws and standoffs BEFORE soldering the switches. The screws will not be accessible once the plate is there and switches are soldered.

coseyfannitutti, 2020-06-04:
>
>
> This repository is currently V1. It will be updated to V2 sometime after pre-orders have been fulfilled.

coseyfannitutti, 2020-06-26:
V2 source and plate files published.

andywarburton, 2020-06-27:
AMAZING!

Closed 2020-06-26.

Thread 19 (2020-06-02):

Question regarding case

ninizheng18, 2020-06-02:
In MechMerlin's "CFTKB Discipline 65% Rebuild with NEW Sandwich Case" build stream, he noted issues with finding a USB-C cable that fit in the hole. Is this something you can fix with the dimensions of the case? If not, I believe you mentioned in the stream that a cable from Zap Cables works, any others?

dhanakane, 2020-09-15:
I am using a USB cable with a heat shrink with no problems. You could create more space by stacking the open layers, or horizontally by making the open layer's opening wider.

The heat shrink cable is something like what you see in [this](https://shop.tokas.co.uk/product/bliss/?v=79cba1185463) picture.

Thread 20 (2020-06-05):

Is the BOM parts list the same for the V2/ISO pcb?

jesusignazio, 2020-06-05:
I would like to build the ISO version from the pcb, but since the source is not yet in this repository and the parts take a lot of time in delivery/shipping, I want to buy it to save time and to have it all when the PCB source is finally available.

Are all the parts the same for V2 compared to the BOM from the V1 pcb?

Thanks!

coseyfannitutti, 2020-06-26:
V2 source has been published. The only difference in the BOM for V1 and V2 is one extra diode for ISO backslash/split left shift.

jesusignazio, 2020-06-27:
THANKS!!

Closed 2020-06-26.

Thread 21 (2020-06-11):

Step 12 in Build Guide says 4x standoffs, should be 6x

runasand, 2020-06-11:
Step 12 in the [Build Guide](https://static1.squarespace.com/static/5c533d33348cd92b886e544d/t/5e9fbf9e58f1fb0b01f71a7c/1587527585202/DISCIPLINE+BUILD+GUIDE.pdf) says:

> 4x M2 10+3mm standoffs (top acrylic)

I believe the correct version is:

> 6x M2 10+3mm standoffs (top acrylic)

kilyn666, 2020-07-03:
In addition, atmega328p and 28 pin IC socket mentioned in the included components should actually be atmega32a and 40 pin IC socket

coseyfannitutti, 2020-08-25:
Updated. Thanks.

Closed 2020-08-25.

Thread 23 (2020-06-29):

What PCB thickness is recommended?

jesusignazio, 2020-06-29:
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

dhanakane, 2020-06-29:
1.6mm should be fine, but 1.2mm makes it a little bit easier to solder. I
would think a slightly thicker plate would help with stiffness if you are
not going to use a switchplate too.

On Mon, 29 Jun 2020 at 07:43, Jesús Ignacio García <notifications@github.com>
wrote:

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

coseyfannitutti, 2020-06-29:
You need to do 1.6mm. Do not do 1.2mm. Screw in stabilizers are intended to be used with 1.6mm PCBs. You would need to make inserts for the stabilizers to use a 1.2mm PCB.

kiwisaurio, 2020-07-02:
hey, I'm trying to print it on jlcpcb but it's my first time printing a pcb and I don't know the size of this pcb, can you post a screenshoot of your pcb setting you placed on jclpcb?

thank you

coseyfannitutti, 2020-07-02:
That is just their gerber viewer timing out. Typically, you can go to File
Manager on JLC and find it there with the gerber preview and click "Quote".

Otherwise you can manually enter the dimensions, which are 305 x 123 mm.

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

kiwisaurio, 2020-07-02:
ok, I just realised what you told me, now I got the question, how many layers should I put? Is this configuration ok?
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

dhanakane, 2020-07-05:
Just a quick follow up to the PCB thickness question and screw in stabilisers. As a first timer, I notice that the stabilisers come with spacers. Would simply adding an additional spacer of 0.4mm or even cutout electrical tape where the screws attach not fix the problem of thinner PCBs? I ask as I have ordered some PCBs at 1.2mm and don’t want them to go to waste. I am also planning on using them with a metal plate for added stiffness, so PCB thickness should hopefully not affect the typing experience too much.

jesusignazio, 2020-08-04:
@coseyfannitutti what about the plate thickness? Is it 1.6mm too? Thanks

coseyfannitutti, 2020-08-04:
@dhanakane You can use [these shims designed by ai03)[https://github.com/ai03-2725/StabilizerShims] to use screw in stabilizers with a 1.2mm PCB. The spacers that come with C3 stabilizers will not be sufficient for this purpose. Those are simply for protecting from shorts if the screw is going in an area near a trace.

@jesusignazio Yes, plate thickness should be 1.6mm as well for switches to be able to clip in properly.

Closed 2020-06-29.

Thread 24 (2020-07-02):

JLC PCB right configuration

kiwisaurio, 2020-07-02:
After searching through the internet a lot, I didn't see anyone posting how to properly print the PCB, so I want to ask if this configuration is ok.

Thank you.
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

coseyfannitutti, 2020-07-02:
It should be changed to the default 1.6mm for the PCB to work properly with
screw in stabilizers. 1.2mm can only be used if you make .4mm inserts for
your stabilizers, which for this particular build is not worth the trouble.

I would also recommend selecting "Yes" for the "Remove Order Number"
option. If "No" is selected JLC will silkscreen an order number onto the
PCB. Unless a specific location is specified they may place it in an area
that may be visible and unsightly on your completed build.

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

kiwisaurio, 2020-07-03:
> It should be changed to the default 1.6mm for the PCB to work properly with screw in stabilizers. 1.2mm can only be used if you make .4mm inserts for your stabilizers, which for this particular build is not worth the trouble. I would also recommend selecting "Yes" for the "Remove Order Number" option. If "No" is selected JLC will silkscreen an order number onto the PCB. Unless a specific location is specified they may place it in an area that may be visible and unsightly on your completed build.
> […](#)
> On Thu, Jul 2, 2020 at 5:30 PM kiwisaurio ***@***.***> wrote: After searching through the internet a lot, I didn't see anyone posting how to properly print the PCB, so I want to ask if this configuration is ok. Thank you. [image: image] <https://user-images.githubusercontent.com/34544227/86410906-f85d6d00-bcbb-11ea-8718-7549a3781d96.png> — You are receiving this because you are subscribed to this thread. Reply to this email directly, view it on GitHub <#24>, or unsubscribe <https://github.com/notifications/unsubscribe-auth/AKJQCCD4S2HBNSRRO7KA7ATRZT37RANCNFSM4OPIHY4A> .

Perfect, really appreciate it, if the remaining settings are ok, the build is complete for me. Really thankful ^^

Closed 2020-07-03.

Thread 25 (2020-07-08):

Will the v1 pcb fit the v2 case?

dhanakane, 2020-07-08:
A 3D printing shop has mentioned that the v1 pcb will not fit the v2 cases. It looks like the layouts are identical bar a couple of standoff holes. Is this accurate please?

coseyfannitutti, 2020-07-08:
Yes, both versions of the PCB will fit in the acrylic case found in this
repository.

The reason for the P3D case not being compatible is the mounting style. The
P3D case uses the tray mount style mounting holes with standoffs. The
mounting holes were shifted slightly on the newer version of the PCB. This
acrylic case, however, does not use those mounting holes, so both versions
are compatible.

On Wed, Jul 8, 2020 at 4:28 PM Dhana Kaneshayogan <notifications@github.com>
wrote:

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

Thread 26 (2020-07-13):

spacing problem

andywarburton, 2020-07-13:
Just a heads up, I tried ordering the plate file from JLCPCB and they rejected it on the basis of:

"the spacing between slot to slot or outline require 4mm at least in case of break off , kindly replace with new file ."

I'll try a few things and see if I can figure out where the problem lies and will update here if I find anything out.

coseyfannitutti, 2020-07-13:
The edge is exactly 3mm from the cutouts because they've told me multiple
times in the past that it needs to be 3mm. The problem lies with whoever
reviewed that file and made up that new number, not the file.

I've had them cut nearly 2000 plates with that spacing with no issues,
though occasionally they will add an extra charge.

You could email them saying you're okay with the risk. You could also try
cancelling and resubmitting to get a different reviewer, which has been
successful for a few people that I've spoken to that have had that issue.
Otherwise, I'd recommend just using someone else to cut the plates.

On Mon, Jul 13, 2020 at 6:52 AM Andy Warburton <notifications@github.com>
wrote:

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

andywarburton, 2020-07-13:
ha ha... funnily, thats pretty much what I ended up doing. I made some tiny tweaks and resubmitted.

andywarburton, 2020-07-14:
You were right, the second reviewer approved and then bumped the price slightly!

Closed 2020-07-14.

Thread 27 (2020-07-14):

Blinking LED?

DippedPretzels, 2020-07-14:
Just soldered a v2 from 2019, but it wasn't recognized in QMK toolbox after the boot and reset button sequence.  The LED just blinks at about 1 Hz.  My guess is it might be a problem with the usb port  soldering as it was done poorly, bit I didn't detect any obvious shorts.  What should the resistance be between the usb pads on the back?  Any idea what would cause a LED blinking?

coseyfannitutti, 2020-07-15:
Well, the LED is not connected to the microcontroller at all. It is running directly off of USB power and pulled down with one of the 1.5K resistors, so you've almost definitely got an issue on your power and/or ground pins on the USB port or possibly the 4.7uF capacitor, which has a pretty tight pin pitch as well.

Closed 2020-08-07.

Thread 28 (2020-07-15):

Issues loading complete files for FR4 plate on pcbway and jlcpcb

IOPNR, 2020-07-15:
Loading .zip files from the plate folder in master files but I'm receiving error messages.

Per jlc "Cannot Identify Board Outline"
Per pcbway "There is no drill file and silkscreen layer."

Am I missing something?

coseyfannitutti, 2020-07-15:
You just need to manually enter the dimensions, 305.9 x 96.4mm. Rounding the numbers is fine, or you can copy and paste those numbers from here. That's just for the instant quote. The true dimensions will be taken from the gerber files.

"There is no drill file and silkscreen layer." - More of a warning than an error. Most PCBs will have drills or silkscreen markings, but this one doesn't. There is nothing on the plate to drill or silkscreen, so that's fine.

IOPNR, 2020-07-16:
Sounds great, thank you!

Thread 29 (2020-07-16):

[Feature request] Is there any ways to solder a 2811 led strip into the pcb, then control it by controller

coadotvn, 2020-07-16:
I just solder it into the power led holes, then control it by a RF remote.
If there is any way to solder a led strip, to be controlled by the pcb, it will be best.

coadotvn, 2020-07-16:
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

IOPNR, 2020-07-19:
That's awesome. What kind of led strip did you use if you don't mind my asking?

coadotvn, 2020-07-21:
> That's awesome. What kind of led strip did you use if you don't mind my asking?

any 5v led strip will works, just solder its pin to power led holes on the pcb, it will works

nhanldtn, 2020-08-27:
You can solder the ws2812's data pin on PIN D0 and define config with QMK firmware. I did it and worked fine

stevenvo, 2020-09-09:
> You can solder the ws2812's data pin on PIN D0 and define config with QMK firmware. I did it and worked fine

Can you pls share where is pin D0?

nhanldtn, 2020-09-10:
you can find it from datasheet. This is 14th pin (RXD -PD0)
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

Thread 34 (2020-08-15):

Origin/license for the USB-C connector symbol/footprint

piit79, 2020-08-15:
Hi @coseyfannitutti, could you please let me know what's the origin/license of the USB4085-GF-A USB-C connector KiCad schematic symbol and footprint used in Discipline? I managed to replace the Mini USB connector on the [Plaid](https://github.com/hsgw/plaid) with this connector (https://github.com/hsgw/plaid/pull/27), but I'm not sure it's OK to use the schematic symbol/footprint and commit it into the Plaid repo.

Thanks a lot!

coseyfannitutti, 2020-08-24:
The USB4085-GF-A footprint that I use is a modified version of the one that was in ai03's USB Type-C library. The symbol I just made myself because at the time his library didn't include one, and I wanted to be sure that the pins would be assigned correctly.

It is absolutely fine for you to use them for Plaid.

piit79, 2020-08-24:
Thanks, much appreciated!

Closed 2020-08-24.

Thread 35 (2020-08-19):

V1 vs V2

alchemistake, 2020-08-19:
I search internet for a difference list. What is updated what is not updated what are the difference?

coseyfannitutti, 2020-08-19:
V2 adds ISO layout compatiblity, a switch plate, and uses stacked acrylic for the foot rather than aluminum cones.

The mounting points for the acrylic guard on the top changed a bit as well with two additional mounting points for more rigidity.

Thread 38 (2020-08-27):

[Feature Request]

nhanldtn, 2020-08-27:

nhanldtn, 2020-08-27:
i added RGB led ws2812 on my keyboard but have done some modified and solder Data wire on MCU pin (Pin D0). So, could you please add the pins out for RGB (VCC, DATA, GND) light purpose

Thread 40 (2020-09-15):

SA Profile keycap binding to bottom corner of case

dhanakane, 2020-09-15:
I was wondering if it was possible to amend the layer of the case (closed layer) so there is a bit more clearance for SA profile keycaps. I have this issue with both the right arrow key and the left CTRL key. I could sand the layer down, but it would be nice to not have to do this.

coseyfannitutti, 2020-09-15:
Are you certain that you have the 2x "discipline-top-2" pieces in the correct orientation?

On those two pieces two of the inner corners are sharper, which are meant to be on the bottom side to allow for keycap clearance.

dhanakane-tw, 2020-09-16:
Mea culpa. That was exactly the problem I had. Thanks for taking a look and giving me a solution.

I wonder if it's possible to use the same type of layer for that specific "shape" unless there is a structural/construction reason to not use the same design for the similar looking layers.

dhanakane, 2020-09-17:
That was exactly it, thanks! Is it not possible to have the same corners for all the closed layers to make assembly simpler?

ph-One, 2020-12-21:
Did the exact same thing. I spent a good bit looking everything over before I realized the subtle difference in the corners. I'm not saying any changes are needed bc I should have looked closer, but just +1'ing that I too dealt with this, and if it was more obvious it would have saved me some time

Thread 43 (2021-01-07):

Some BOM parts OOS

pand06, 2021-01-07:
There are a few items on the BOM list that are OOS and I was wondering what if there are alternatives or other version of them that would work.

SuperNici, 2021-05-02:
Which ones are you talking about?

SuperNici, 2021-05-06:
What a coincidence! I ordered on mouser today aswell!

Because i didnt want to wait till june 7 i decided to go with [this](https://www.mouser.ch/ProductDetail/667-ECE-A1HKA4R7) capacitator which will hopefully work the same.

Also make sure you got the right ic which would be [this one](https://www.mouser.ch/ProductDetail/556-ATMEGA32A-PU). Untill yesterday it was wrong in the BOM so make sure you ordered the right one.

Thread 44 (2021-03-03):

Breakout header for unused pins and moving col pins

tott, 2021-03-03:
Cosey, first off - thanks for a great keyboard. I've been playing around with my discipline v2 and have been adding RGB underglow recently. Sadly adding this in VIA is a bit of a chore as you need to apply a custom json definition every time you load VIA.
While digging into this I was also looking into adding a oled display as this keyboard is a dream for adding additional components like this with only alterations to the Acryllic PCB cover to allow housing either a oled display or a rotary encoder or the like.

It would be great though if there would be a breakout header to access the unused pins of the MCU and while at it, it would be awesome to move PC0/PC1 (col13, col12) to PC7/PD0 or other available ports to free up the i2c ports of the MCU.

If you could incorportate this I think a valid next step would be to enable these hidden features in the VIA configuration so they are available out of the box.

If you'd like to approach this I'd be happy to offer my assistance.

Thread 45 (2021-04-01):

Personal build information/help

debo, 2021-04-01:
Hi @coseyfannitutti I'm writing to you because, as per subject I'd like to build the Discipline v2 by myself but by being completely new to the hobby, I'm not quite sure where to go to get the parts manufactured, specifically the pcb/plates and the acrylic case.

If my understanding is correct, based on the online stream I saw with MechMerlin you usually use JLC PCB for prototyping and Elecrow for the final product, is that correct? In a normal scenario both the bottom and top plate are made of PCB material? Just to understand if I can get them made all by Elecrow.

About the acrylic instead, I understand from the documentation that you use Ponoko instead. Is that correct too?

One more question, I notice in the photos that there are various engraving on the components are those part of the gerber and dfx files already or do I need to modify something else?

Last but not least, when I use JLC PCB/Elecrow, are there settings on their tool that I have to change other than the colour of the PCB?

Thanks a lot for your time and help.

SuperNici, 2021-05-08:
Im currently in the process of building this keyboards as well, I feel like I understand the process well enough to answer some of your questions.

> you usually use JLC PCB for prototyping and Elecrow for the final product

Prototyping is not required unless you modify the PCB yourself and since coseyfannitutti's design has been thoroughly tested you can skip the Prototyping step all together and order straight from JLCPCB or Elecrow, although most people i know ordered from JLCPCB.

debo, 2021-05-09:
Thanks a lot @SuperNici this was super super helpful, really appreciated.

robopuff, 2021-06-25:
Hey guys, I am buildong it for myself as well and I've used JLCPCB and it looks and works well. It was not easy for me to get proper M2 screws and standoffs since no store would sell one with correct size and esthetically pleasing - aliexpress worked fine for it. With that I've also ordered steel plate and it is a blast to use!

Now I need to cut just the plexi and was wondering if you know correct thickness @SuperNici for the kitfoot?

fourstepper, 2021-11-06:
@SuperNici would you care to elaborate how you handled the top plate? Looking at my order, the size doesn't get correctly detected by jlcpcb. Any ideas? Thank you a lot :)

robopuff, 2021-11-06:
You can get the dimensions of the top plate from laser cut files, can't remember what they are right now but I've used it to cut in steel plate and it fits perfectly

fourstepper, 2021-11-06:
Sorry for my ignorance, I am still quite new to this. Which files are the laser cut files? Thank you a lot

robopuff, 2021-11-06:
> Sorry for my ignorance, I am still quite new to this. Which files are the laser cut files? Thank you a lot

No worries, I had a million questions when I've built mine 😅

You can check it here https://github.com/coseyfannitutti/discipline/blob/master/plate/discipline-plate-lasercutting.dxf

fourstepper, 2021-11-06:
Thank you, that worked!

SuperNici, 2021-11-06:
Personally I made my discipline plateless, see [my reddit post ](https://www.reddit.com/r/MechanicalKeyboards/comments/qmvntb/comment/hjc6ruf/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). In hindsight I regret not having ordered plates, but it works just fine without one.

The file you imported was the Gerber file, the missing dimensions should be the same as for the PCB itself, in this case:

`122.81 * 304.89`

This is an issue with the generated Gerber file, I tried fixing it and had no luck. I'll open an issue in just a second.

PS. @fourstepper you just replied while I was writing this comment, i'll still post it if others have the same issue :)

robopuff, 2021-11-06:
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

Isn't PCB taller than the plate? I mean it's not covering the electronic components but rather just the keys

SuperNici, 2021-11-06:
Oh I totally forgot about that, my bad. It would probably still arrive fine, you'd just pay more... (JLCPCB would just waste a bunch of extra Fr4 Material since the keyboard plate itself gets cut out of the specified size)

What measurements did @fourstepper use? I'll update my comment accordingly.

fourstepper, 2021-11-06:
I used the measurements from the acrylic top plate as suggested by @robopuff, which reports 305.7 x 96.2 mm. Seems like that could work?

SuperNici, 2021-11-06:
Thanks, that looks about right, I updated [the issue I opened](https://github.com/coseyfannitutti/discipline/issues/60) ( ´ ▽ ` )b

fourstepper, 2021-11-06:
Thank you!

robopuff, 2021-11-06:
>
>
> I used the measurements from the acrylic top plate as suggested by @robopuff, which reports 305.7 x 96.2 mm. Seems like that could work?

I've just checked against what service provider I've used sent back to me and indeed it was 305x96mm JLCPCB have their checks done before accepting a job so maybe they would take a look into it as well before misprinting/cutting/etc things 😅

fourstepper, 2021-11-06:
@robopuff I have a lot of time and have some screws and standoffs already, as I am also in the process of building a CRKBD. Thank you for the recommendation though!

SuperNici, 2021-11-07:
> I've just checked against what service provider I've used sent back to me and indeed it was 305x96mm JLCPCB have their checks done before accepting a job so maybe they would take a look into it as well before misprinting/cutting/etc things 😅

@robopuff i dont think it should matter too much as long as it is big enough, the exact cutting measurements are taken from the gerber file after all so it really should not be a problem

NiciTheNici, 2023-05-27:
Heyall, just out of curiosity... How many of you ended up building this keyboard? Got any pics?

Heres mine!
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

robopuff, 2023-05-27:
Daily driven since built, use U4T switches with steel plate, it's a joy to use.

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

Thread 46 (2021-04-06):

USB-C connector detaching

TheStockie, 2021-04-06:
I've been having problems with the USB-C cable tearing the connector off the PCB, I was wondering if people have encountered this problem and what you've done to prevent this.

Thanks a lot for the help!

wiebel, 2021-05-03:
Have you soldered on the larger tabs? I can't imagin the connector gfetting detached without breaking the pcb. You have to apply liberal amount of heat (high wattage and/or longe heating time) to those tabs and the connected ground plane due to it's high thermal mass to get the solder flowing. But if done properly  you shouldn't be able to simply "tear" it out.

coseyfannitutti, 2021-05-05:
The four feet on the bottom if fully soldered should be more than enough to hold it in place and would require quite a bit of force to break. It's possible that if you did solder those four feet that perhaps they were cold joints that weren't fully soldered.

Closed 2021-05-05.

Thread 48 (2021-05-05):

BOM Guide False

SuperNici, 2021-05-05:
There is an Error in the BOM. Comparing it to the [pdf build](https://static1.squarespace.com/static/5c533d33348cd92b886e544d/t/5f4597da4c8f740579aec0ca/1598396382120/DISCIPLINE+BUILD+GUIDE.pdf) guide there is a difference between the IC's used. In the BOM a ATMEGA32**P**-PU is mentioned under the Part column (the one for the discipad), this is wrong. What it should be is a ATMEGA32**A**-PU as mentioned in the Query column.

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

This is a critical flaw for everyone using the BOM as it makes the end product unusable because of it.

coseyfannitutti, 2021-05-05:
Fixed. Not sure how that changed, but I've changed it back.

Closed 2021-05-05.

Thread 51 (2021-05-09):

Screw type not clear

SuperNici, 2021-05-09:
The type of screws needed is not listed anywhere besides in the [build guide PDF](https://static1.squarespace.com/static/5c533d33348cd92b886e544d/t/5f4597da4c8f740579aec0ca/1598396382120/DISCIPLINE+BUILD+GUIDE.pdf) (page 4)

I do not understand what type of screw is meant by ***6x M2 10+3mm standoffs***
I would think it means ***6x m2x10mm screws*** and ***6x 3mm standoffs*** but I am not sure.

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

Armastardo, 2021-05-16:
That's the correct name. The standoff you're looking for is the one in your picture:
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

omniphx, 2021-05-20:
10+3mm standoff = male-female
6mm standoff = female-female

SuperNici, 2021-05-20:
Thank you, this helps a lot!

Closed 2021-05-20.

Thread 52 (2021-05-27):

Help with Bootloader/ Flashing

mishnoc, 2021-05-27:
Hello, I recently acquired some discipline 65 pcbs and parts and have soldered one together. I am now at the point where i need to flash the micro controllers. However I have no clue how to go about this. I have a usbasb programmer (https://www.amazon.co.uk/gp/product/B06XYV162N/ref=ppx_yo_dt_b_asin_title_o08_s00?ie=UTF8&psc=1) and have downloader winavr but after that I am completly lost. I have no experiance at all with this kind of thing. Any help would be greatly appreciated.

khail-k, 2021-05-27:
Does this help?
https://static1.squarespace.com/static/5c533d33348cd92b886e544d/t/5e9fd1d198a4166c9ccc5b68/1587532241535/DISCIPLINE+VIA+GUIDE.pdf

alkeeb, 2021-05-27:
Do these help?

Bootloader:
https://github.com/coseyfannitutti/discipline/tree/master/doc/bootloader

Flashing VIA guide:
https://static1.squarespace.com/static/5c533d33348cd92b886e544d/t/5e9fd1d198a4166c9ccc5b68/1587532241535/DISCIPLINE+VIA+GUIDE.pdf

mishnoc, 2021-05-28:
Thanks for the reply. Im fairly sure the micro controllers are blank. I tried to follow the bootloader instructions but honestly have no idea what I'm doing.

jesusignazio, 2021-05-29:
> Thanks for the reply. Im fairly sure the micro controllers are blank. I tried to follow the bootloader instructions but honestly have no idea what I'm doing.

Hi.

In this issue you have info. https://github.com/coseyfannitutti/discipline/issues/6 and in the guide too.
The only point is that you have to change the line 41 in the Makefile.inc file to 'PROGRAMMER = -c usbasp' if you are going to use an usbasp flasher.

@alkeeb you need special hardware in order to flash the bootloader if you have bought a new microcontroller. Once you have a bootloader, you will be able to use the programming buttons of the keyboard.

alkeeb, 2021-05-29:
@jesusignazio I have spent some time looking into this and yes I would need to flash a bootloader. Maybe you can help answer some questions I have:

- Can I flash USBaspLoader with an arduino or is it limited to the arduino bootloader; if so will the arduino one work for this project?

- AVR or ISP programmer, does it matter? I have not found any good descriptions on this, just that each one supports a different chip. I know that coseyfannitutti used an AVR.

- What are the pins on the PCB for?
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
Can I connect the programmer to this or do I need a breadboard circuit like in all the tutorials.

jesusignazio, 2021-05-29:
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

This is how I flashed it:

–I used an usbasp programmer, the same you linked in the OP.
–I connected the usbasp to the keyboard (in the three pins you asked) and to the USB from PC aswell.
–The software stuff: Download avrdude, clone the usbasploader repository (is important to clone the correct branch). I have read that there is a common problem with drivers in Windows, but I use Linux so I can't help you in this.
–Modify the line in Makefile.inc file to 'usbasp' in order to make the usbasp work.
–Run make and make install commands in avrdude.
–Once the bootloader is flashed, the usbasp won't be necessary anymore.
–Connect the keyboard to the PC with an usb keyboard and use the two buttons from the keyboard to flash VIA.

alkeeb, 2021-05-30:
That clears up a lot, thank you.

mishnoc, 2021-05-31:
After some trial and error I finally managed to get my controller flashed. Huge thanks to both of you for the help <3.

Closed 2021-06-02.

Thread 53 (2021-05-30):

Alternative Part

cozmiz, 2021-05-30:
Hi, I would like to ask if there is any alternative part. Some of the components are out of stock and will only be in stock in ten or more weeks. The part in question in the 4.7uF Capacitor (UMT1H4R7MDD) and the 16mhz crystal (ABL-16.000MHz-B4Y). I was only able to get my hand on the PCB v1 and the backplate.

jesusignazio, 2021-05-30:
- https://es.aliexpress.com/item/1005002075527957.html
- https://es.aliexpress.com/item/1005002562834681.html

cozmiz, 2021-05-30:
would this work https://www.digikey.com/en/products/detail/abracon-llc/ABL-16-000MHZ-B2/675236 for the 16mhz crystal?
and this https://www.mouser.com/ProductDetail/667-ECE-A1HKA4R7 for the 4.7uf Capacitor?
I am not sure if I want to wait for 30-50 days for the components to arrive via aliexpress.

mishnoc, 2021-05-31:
I bought some parts recently and used this, https://www.mouser.ie/ProductDetail/Panasonic/ECE-A1HKS4R7?qs=rMMd5vBiahogzu%252BjM7Ehlw%3D%3D. Similar to what you linked but is the same size as the one in the BOM. It worked fine for me.

Closed 2021-06-01.

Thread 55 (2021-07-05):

FIrmware flashing help

alkeeb, 2021-07-05:
I finished soldering and wanted to test the board. On linux I followed the steps and installed the bootloader and ran it. I got. Message saying it was fine. I then went to windows and tried to use QMK toolbox to upload VIA firmware but when I try to get into the bootloader mode nothing happens.

I have tried holding boot, taping reset and releasing boot. And hold boot when plugging in. but QMK does not get any message, nor does device manager show me anything.

I I was spamming the buttons and QMK showed a message once and I cant get it back again.

The only part I swapped was ABL-16.000MHz-B4Y for ABL-16.000MHz-B1U as the B4Y was out of stock. but this should not have caused the problem.

The best part: I tried reflowing the usb port and checking for shorts. I left the board plugged in for 5 mins and found smoke coming from the cap and or usb port. Im just glad I was there to put it out. This is the 2nd board I have broke and I only have 3 left, it also took out the usb cable.

Any advice on what went wrong, was it the crystal that caused some problem?

Closed 2021-07-08.

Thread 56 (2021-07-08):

usb 3.0 vs 2.0

alkeeb, 2021-07-08:
I just burnt my 3rd board.

I am starting to think there is a problem with usb. Has anyone had problems with usb 3? does it supply too much current?

coseyfannitutti, 2021-07-15:
No, there is not any issue with overcurrent inherently in the PCB design. The USB port used in the BOM, which is only USB 2.0 capable, as well as the pull down resistors on the CC pins should limit current to 5V/500mA.

tifanrepo, 2021-07-21:
could you please post an update on the orders? people are starting to get pretty angry on  /mk and will start claims to their ccs

Closed 2021-07-14.

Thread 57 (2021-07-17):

Discipline V2 Groupbuy

charles0917, 2021-07-17:
Hi a lot of people have not uet received their discipline V2 from last November's groupbuy. Can you please give an update whether they will be shipped? Last update you gave was from over three months ago. Thanks.

charles0917, 2021-07-28:
@coseyfannitutti So I'm assuming you just decided to keep the money and not give the products? Pretty sure that decision will hurt you down the road as you've broken the law.

coseyfannitutti, 2021-07-29:
That's absolutely not my intention at all. About half the orders have already gone out, and a lot (hopefully the remainder of all outstanding orders) will be going out in the next week.

I know this has been a rough rough group buy to say the least. Several unforeseen delays and trying to do it all myself got the best of me on this one. I understand that everyone that's contributed to this project works hard for their money, and moving forward I intend to make a more pointed effort to respect the fact that you've spent your hard earned dollars at the store and also bring in some help with packing and sorting.

zanderc1, 2021-07-30:
Hey man, really hope you’re doing well during these tough times. A lot of people are still checking on the website for updates. Are you planning on making an update about this groupbuy on that website soon? I thought it would help with some people out with their concerns.

ningyuuu, 2021-07-31:
@coseyfannitutti thanks for checking in! I was a little worried you were facing some health issues during this period, but glad to hear everything is well. Will patiently wait for the order to deliver.

tifanrepo, 2021-08-01:
> @coseyfannitutti Hey man, really hope you’re doing well during these tough times. A lot of people are still checking on the website for updates. Are you planning on making an update about this groupbuy on that website soon? I thought it would help with some people out with their concerns.
>
> (EDIT): Theres a on-going subreddit about this topic and a lot of people wanted an update about the groupbuy from the website and a lot of people are still worried about their orders and they (seem) that they want an update about it in the website.

Same thing here. Many people are wondering what its going since there have been no updates for months now. Could you please give a general statement?

thank you

marc-fez, 2021-08-03:
> That's absolutely not my intention at all. About half the orders have already gone out, and a lot (hopefully the remainder of all outstanding orders) will be going out in the next week.
>
> I know this has been a rough group buy to say the least. Several unforeseen delays and trying to do it all myself got the best of me on this one. I understand that everyone that's contributed to this project works hard for their money, and moving forward I intend to make a more pointed effort to respect the fact that you've spent your hard earned dollars at the store and also bring in some help with packing and sorting.

@coseyfannitutti much appreciated, thanks for the update. I know times are tough and stuff happens but if you could toss a note on the pre-order updates page once a month or so most of us would be cool with it. We get that long lead times and delays are part of this hobby. It's the total silence that is concerning.

charles0917, 2021-08-18:
So another 3 weeks has passed, has anyone gotten any updates?

bean-ders, 2021-08-18:
>
>
> So another 3 weeks has passed, has anyone gotten any updates?

No, I sent an email 3 weeks ago as well after viewing this thread. If I could just get a response, I do not care if this takes another 6 months - as long as this comes in at some point and is still being tracked.

tifanrepo, 2021-08-18:
With this radio silence is hard to believe everything is going ok. I have decided to do a credit card chargeback. This situation has shown everything but respect for the customer. I mean, We are discussing this on a GITHUB ISSUE, for gods sake.

maxim-sm, 2021-08-18:
@coseyfannitutti I don't want to come off as rude but I really feel that I need to say this. I really don't understand why it is so hard to write a quick update on the main website. You wrote, "...and moving forward I intend to make a more pointed effort to respect the fact that you've spent your hard earned dollars at the store...", but you still refuse to update the website after several requests, although it will clearly show the respect you're talking about.

Please take a look at these two Reddit threads, [here](https://www.reddit.com/r/MechanicalKeyboardsUK/comments/oc9go2/has_anyone_in_the_uk_received_their_discipline/) and [here](https://www.reddit.com/r/MechanicalKeyboards/comments/m3mldw/cftkb_discipline_v2/). Please read the confusion and frustration of the people who bought the kit that could've been avoided with a few short updates.
Moreover, on the page for the Discipline, you state that "Delays are possible, but you will be notified in a transparent manner if any such delays occur". No update since April is not, in any way, to be notified a transparent manner.

And I'm not even mentioning all the people that emailed you for support with the kit or help with lost packages, and didn't get any response for several months. Or the issues that are opened in this repository without an answer.

Again, I'm sorry if all of this sounds rude or aggressive, but this situation is really frustrating. At this point I just hope to receive the kit without any issues because I know I will wait another half an year for a reply.

zanderc1, 2021-08-20:
@coseyfannitutti Hey man, trying to check in with you. Is everything okay and stuff? I don’t wanna come off rude but some haven’t received an update since 3 weeks ago when you said it was gonna ship the week after. And most people who does not know about this GitHub thread are starting to think that you ran off with the money. Any update will help your customers a lot, even if its a simple “Sorry about the very quiet 3 months as I was working hard to get these orders out..etc.” That would also help more younger customers who purchased this with a visa gift card from their hard earned cash, and the people who still have hope in you that you would send out all of the orders.

We REALLY don’t care how much you would take to get the orders out. Hey, it might take 10 months more. We just need updates about it so we know where our product is and if our hard earned cash isn’t getting stolen.

Really hope the you would read this, make and update and stuff. Or don’t. We can’t control you. But keep in mind, a lot of people are getting frustrated.

bean-ders, 2021-08-28:
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

I receive mine without any shipping notice/email response out of the blue.

I agree, radio silence is the worst way to deal with this. Being open and honest gets you far in the community. Most reasonable people will understand delays, especially with current supply shortages and shipping backups.

d-daemon, 2021-09-13:
@coseyfannitutti Can you please provide an update on the website on your status? I've sent you multiple e-mails about updating my shipping address with no response. Would allowing us to cancel our orders and getting a refund help alleviate your own personal workload? Any update would be greatly appreciated as the community is quite upset over this GB. Any communications is better than no communication, thanks.
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
lhoste, 2022-11-09:
> If anyone is still following this issue and hasn't received thier keyboard. Yesterday I got a "back in stock" email for mysterium V2. So, it seems he's back in action and selling stuff. But atleast I'm still missing my discipline V2 kit.

Incredible news if he commit to it. Most of us in this thread are waiting for some form of communication.

kkurtson, 2022-11-09:
maybe one can write a warning in the mysterium github?

SimRicard, 2022-11-09:
I'm keeping an eye out for any posts advertising the sale on the mechanical keyboards or mechmarket subreddit, definitely not going to let this pass by without comment.

knorr3, 2022-11-09:
It's sold out again on the website.

itisibecky, 2023-03-06:
Anyone else still not received their order? I've sent an absurd amount of emails at this point, receive no response, no order, nothing.

itisibecky, 2023-03-06:
@coseyfannitutti Any update? It's been three years... at this point just refund me!!

goobzilla, 2023-03-06:
> Anyone else still not received their order? I've sent an absurd amount of emails at this point, receive no response, no order, nothing.

Nope, never recieved my order or any response to any of the emails I have sent. I have sent 17 emails at this point from May 2021 to date.

All I want is a refund....

@coseyfannitutti cmon dude.

j-dabrowski, 2023-05-14:
I also never received my board or any responses to email queries
Does anyone know what legal action is possible from Australia?

chriswade, 2023-05-14:
> I also never received my board or any responses to email queries Does anyone know what legal action is possible from Australia?

I'm not sure, I did have a look into state law in Florida to see if there was anything we can do to get out funds back, however found nothing. If anyone here lives in Florida, let me know.

chriswade, 2023-05-14:
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

At this stage, I would take an acknowledgement of the situation. @coseyfannitutti

lhoste, 2023-05-14:
Just saw this :

The cftkb.com website has expired.

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

I guess all we can do is to take the L at this point.

knorr3, 2023-05-18:
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

It's back up again.

tifandev, 2023-05-18:
This dude is f****n evil. I assure he is reading this comment chain and he
saw the website was down because of us. Take responsibility a**hole.

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

jossh-h, 2023-06-03:
> I also never received my board or any responses to email queries
Does anyone know what legal action is possible from Australia?

Also in Australia and have no order or response to my emails, can't even get a refund

NiciTheNici, 2023-07-11:
@tifandev
> This dude is f****n evil. I assure he is reading this comment chain and he
saw the website was down because of us. Take responsibility a**hole.

Nahh, thats crossing the line. Coseyfannitutti has been nothing but excellent when it comes to this project and that's the hill I'm willing to die on.

He definitely fumbled the group buy and the only thing I blame em for is the lack of communication. Group buys are bloody hard and so much pressure especially for a single individual. And you calling them evil over a bloody keyboard is ridiculous man.

Judging by how coseyfannitutti hasnt been active in almost an entire year, not just in this thread, but also with PRs, Issues and anything else this leads me to believe that theres something else going on, especially considering how ready they were to help when I started this build.

To my knowledge there hasnt been another group buy since yours unlike someone mentioned above, thats BS.

I sincerely hope that coseyfannitutti is doing fine and eventually sorts this out. You deserve your keyboard or your money back. This nastyness does not help so please cut it out.

kkurtson, 2023-07-11:
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

I can't believe we are still discussing this. I have written off the 90 USD as a loss. The fact is that the seller has consistently ignored all customers, which is unacceptable. Speculating briefly, we are probably talking about a sum of over 20,000 USD that is outstanding, which is no small thing. From my point of view, the community is right to make sure that the seller cannot repeat this.

itisibecky, 2023-07-11:
agreed 100%. it's theft to take people's money and not provide the agreed
upon item or service and then disappear off the face of the earth

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

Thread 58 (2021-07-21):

Troubleshooting issue with strange key behavior

the-mianaai, 2021-07-21:
Hi, I'm hoping for help in tracking down and fixing a problem with a V2 board. The PCB itself was ordered from JLCPCB and the parts for Mouser, but I haven't had any issues with any of the other boards in the batch (I made a few as gifts for friends)

The issue: Intermittently, when using the 3 key, the board will output 31 or 13; QMK Configurator board tester indicates a nearly equal time registering the two keycodes. This may or may not be accompanied by the 1 key not working at all. The person who was gifted the board reported similar issues with D triggering A, but I have not been able to reproduce that with extensive testing.

What I've tried:
- Reseating the microcontroller and checking for bent pins
- Swapping microcontrollers
- Reflashing the microcontroller
- replacing the diodes for those switches
- Visual inspection of the board for shorts, bridges, scratches
- Cleaning the PCB thoroughly to remove flux residue
- Reflowing the solder on the USB port
- Using a multimeter to test the R1-C2 and R1-C4 circuits while bridging the pads for the 1 or 3 keys

All of the above has either not fixed the problem or indicate that the board should be fine. My conclusion is that the most likely place for the problem is in the microcontroller socket, particularly since the C2 pin is directly in between the R1 and C4 pins, and somehow connecting the R1-C4 circuit creates a short inside the socket that also connects the R1-C2 circuit. I think this doesn't quite explain the issue with 1 not registering when pressed on its own, but I may be misunderstanding something. It also doesn't quite make sense to me why nothing else on C2 is having a problem (other than the reported C2/C4 and R3 problems that I haven't been able to reproduce, but the R3 pin is immediately next to the R1 pin, so maybe there is an issue, just a more intermittent one)

If this is the case, I'm wondering what my best options are. Desolder the socket and replace it (extremely not fun)? Disconnect the C2 and/or C4 pin(s), connect the traces to unused pins, and rewrite the firmware (not ideal as the person this was gifted to doesn't have extensive expertise with QMK and would have to rely on me for future firmware customization)

I'm open to all suggestions regarding possible causes for the problem and possible ways to fix it, and any assistance is greatly appreciated.

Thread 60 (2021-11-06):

Plate PCB Gerber missing dimensions

SuperNici, 2021-11-06:
### How to Reproduce:
Upload the [plate Gerber.zip](https://github.com/coseyfannitutti/discipline/blob/master/gerber/plate/discipline-plate.zip) to JLCPCB. The Dimensions should be `122.81 * 304.89` yet are blank.

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

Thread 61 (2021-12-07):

Is the discipline65 v2 pcb compatible with the case that the v1 comes in?

onlyoreo1212, 2021-12-07:
@coseyfannitutti
Hi, was wondering if the discipline65 v2 pcb is compatible with the v1 case? Asking because I managed to burn the pcb on the v1 and looking to purchase another set of v2 but I really like the case look..
Thanks!

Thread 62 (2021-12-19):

Suggestion how to make discipline 65 more available to people outside of the USA

jovansijacki, 2021-12-19:
When I saw your design I must admit I fell in love.
But since I live in a country outside of the EU, the parts you recommended are scarce, expensive, and hard to find. I managed to find almost all parts on aliexpress, but one major problem persists.
I can't find the USB Type C connector part, the only option that even ships to my country is from mouser but the shipping is 10times the amount of the part (40USD shipping fee for a 4 dollar part).
So I am asking you is it possible to make an alternative design with a more mainstream connector board like this one I found on aliexpress for example.
( https://www.aliexpress.com/item/1005001300974530.html?spm=a2g0o.cart.0.0.3a7a3c00jCdf6k&mp=1 )
It could also look cool if it was mounted on some pins.
I know this is a long shot but I had to try.
Thanks in advance,
Jovan

jesusignazio, 2021-12-19:
https://github.com/coseyfannitutti/discipline/issues/36

jovansijacki, 2021-12-19:
Does the one you linked from aliexpress work?
I am currently on fiver looking for people who could modify the design, but this Is a cheaper option

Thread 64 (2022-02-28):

Discipline v1 files needed

jovansijacki, 2022-02-28:
I bought a bunch of discipline v1 PCBs with almost all electronic components from a friend (He needed only one but you can print a minimum of 5 PCBs on jlcPCB). I cut shields from acrylic but v1 PCB is not compatible with v2 shields is there any way to find original v1 shields to cut?

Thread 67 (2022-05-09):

Connection issues on macOS

steakscience, 2022-05-09:
I'm encountering some connection issues when connecting a Discipline to a Mac.

At the login screen, the keyboard will work. After logging in, the keyboard will stop working and needs to be reconnected. I can reliably reproduce this 100% of the time.

This issue does not happen with other keyboards. It also does not happen with this keyboard on other OSes.

I was wondering if anyone else has had these issues or knows how to fix them. Thanks!

BenRoe, 2022-05-09:
Never had a similar problem.
Do you use a special firmware, or bootloader?
Try different usb port (without hub) and cables.

steakscience, 2022-05-09:
> Never had a similar problem.
> Do you use a special firmware, or bootloader?
> Try different usb port (without hub) and cables.

I have tried both:
- USB C <-> USB C
- USB A <-> USB C hub

I am (probably) using the latest VIA version, flashed a few months ago

BenRoe, 2022-05-09:
Try vial. It‘s open source, actively developed and has more features.
https://get.vial.today/

Still a strange behavior. Don’t know what it could be.

dhanakane, 2022-05-09:
Does hitting the reset button force the keyboard to register? I had a similar issue when switching inputs using a hub, and hitting reset when switching inputs fixed it.

Sent from my iPhone

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

steakscience, 2022-05-12:
> Does hitting the reset button force the keyboard to register? I had a similar issue when switching inputs using a hub, and hitting reset when switching inputs fixed it.

Before I try this, RESET will not reset the configuration right?

dhanakane, 2022-05-12:
No. You need to flash the keymap to do that and that involves putting the keyboard into bootloader mode.

Sent from my iPhone

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

steakscience, 2022-05-19:
> No. You need to flash the keymap to do that and that involves putting the keyboard into bootloader mode.
> […](#)

I've verified that pressing Reset after losing connection doesn't do anything

dhanakane, 2022-05-19:
Are you using VIA or something else? AFAIK, hitting reset forces the board to re-register.

If you’re using VIA and reset isn’t forcing the board to re-register then I’m out of ideas unfortunately. Maybe check the previous issues reported if there’s a fix?

Sent from my iPhone

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

NiciTheNici, 2023-07-10:
Did you manage to figure this out?

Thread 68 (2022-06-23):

Could not connect to computer after unplug

coadotvn, 2022-06-23:
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

Everything works fine until I disconnect the cable, then connect it again, it stop working, the LED still on, but can’t type on it.

If I wait for 10 minutes, then connect it again, it will works again.

I try many things but can not make it to work as expected. (includes ATMEGA chip changing, press reset switch, reflash, reboot, …)

Anyone know what should I do, or which component need to be replaced, or how to debug them?

Thank in advanced, this is really good board, awesome opensource project too. I want to fix it, and stick with this board my life long.

quadge, 2023-08-01:
I've got the same issue, I think it was an error in the flashing process but I don't know.

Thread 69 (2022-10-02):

Acrylic Case Build Guide

ElectricRanger3952, 2022-10-02:
I'm trying to make the acrylic case, I know you need the layers of acrylic and screws/standoffs, but I don't know which layers should go where/where to screw which standoff. I can't seem to find any instructions/build guide for the case itself anywhere in the repo. Could someone point me to where I could find a build guide for the acrylic case?

NiciTheNici, 2023-07-10:
I'm fsarly sure the order of those acrylic pieces is supposed to go like @coseyfannitutti wrote in this ordered list:
https://github.com/coseyfannitutti/discipline/tree/master/acrylic-case#part-dimensionsthickness-top-to-bottom

Considering theres only 3 screwtypes needed for that case I'll assume that youll figure it out :)

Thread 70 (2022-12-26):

Discipline inspired DIY Keyboard Troubleshooting

Steven2k6, 2022-12-26:
Hez, I designed and built a Keyboard, but I have some issues with the usbasp bootloader. When I connect the Keyboard to my pc, it says "Device Descriptor Request Failed" in the device-manager. I don't have the two zener diodes on my keyboard, are they the problem?
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
Edit: I use 3.3 instead of 5 volts, because I found out, that the keyboard doesn't work at all with 5 volts.

NiciTheNici, 2023-07-10:
Heya, did you manage to fix this? I'm mildly interesting in designing my own keyboard in the future too and this seems rather important :)

Steven2k6, 2023-07-10:
> Heya, did you manage to fix this? I'm mildly interesting in designing my own keyboard in the future too and this seems rather important :)

There where two 3.6V diodes missing on the data lines.

Closed 2023-08-22.

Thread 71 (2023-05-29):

Discipline Plate V2?

syenasweta, 2023-05-29:
Can I use the plate https://github.com/coseyfannitutti/discipline/blob/master/gerber/plate/discipline-plate.zip for Discipline PCB V2?

NiciTheNici, 2023-07-06:
Yes you can, if you look at commit b40bc8f it shows that the plate has been updated to the V2 version

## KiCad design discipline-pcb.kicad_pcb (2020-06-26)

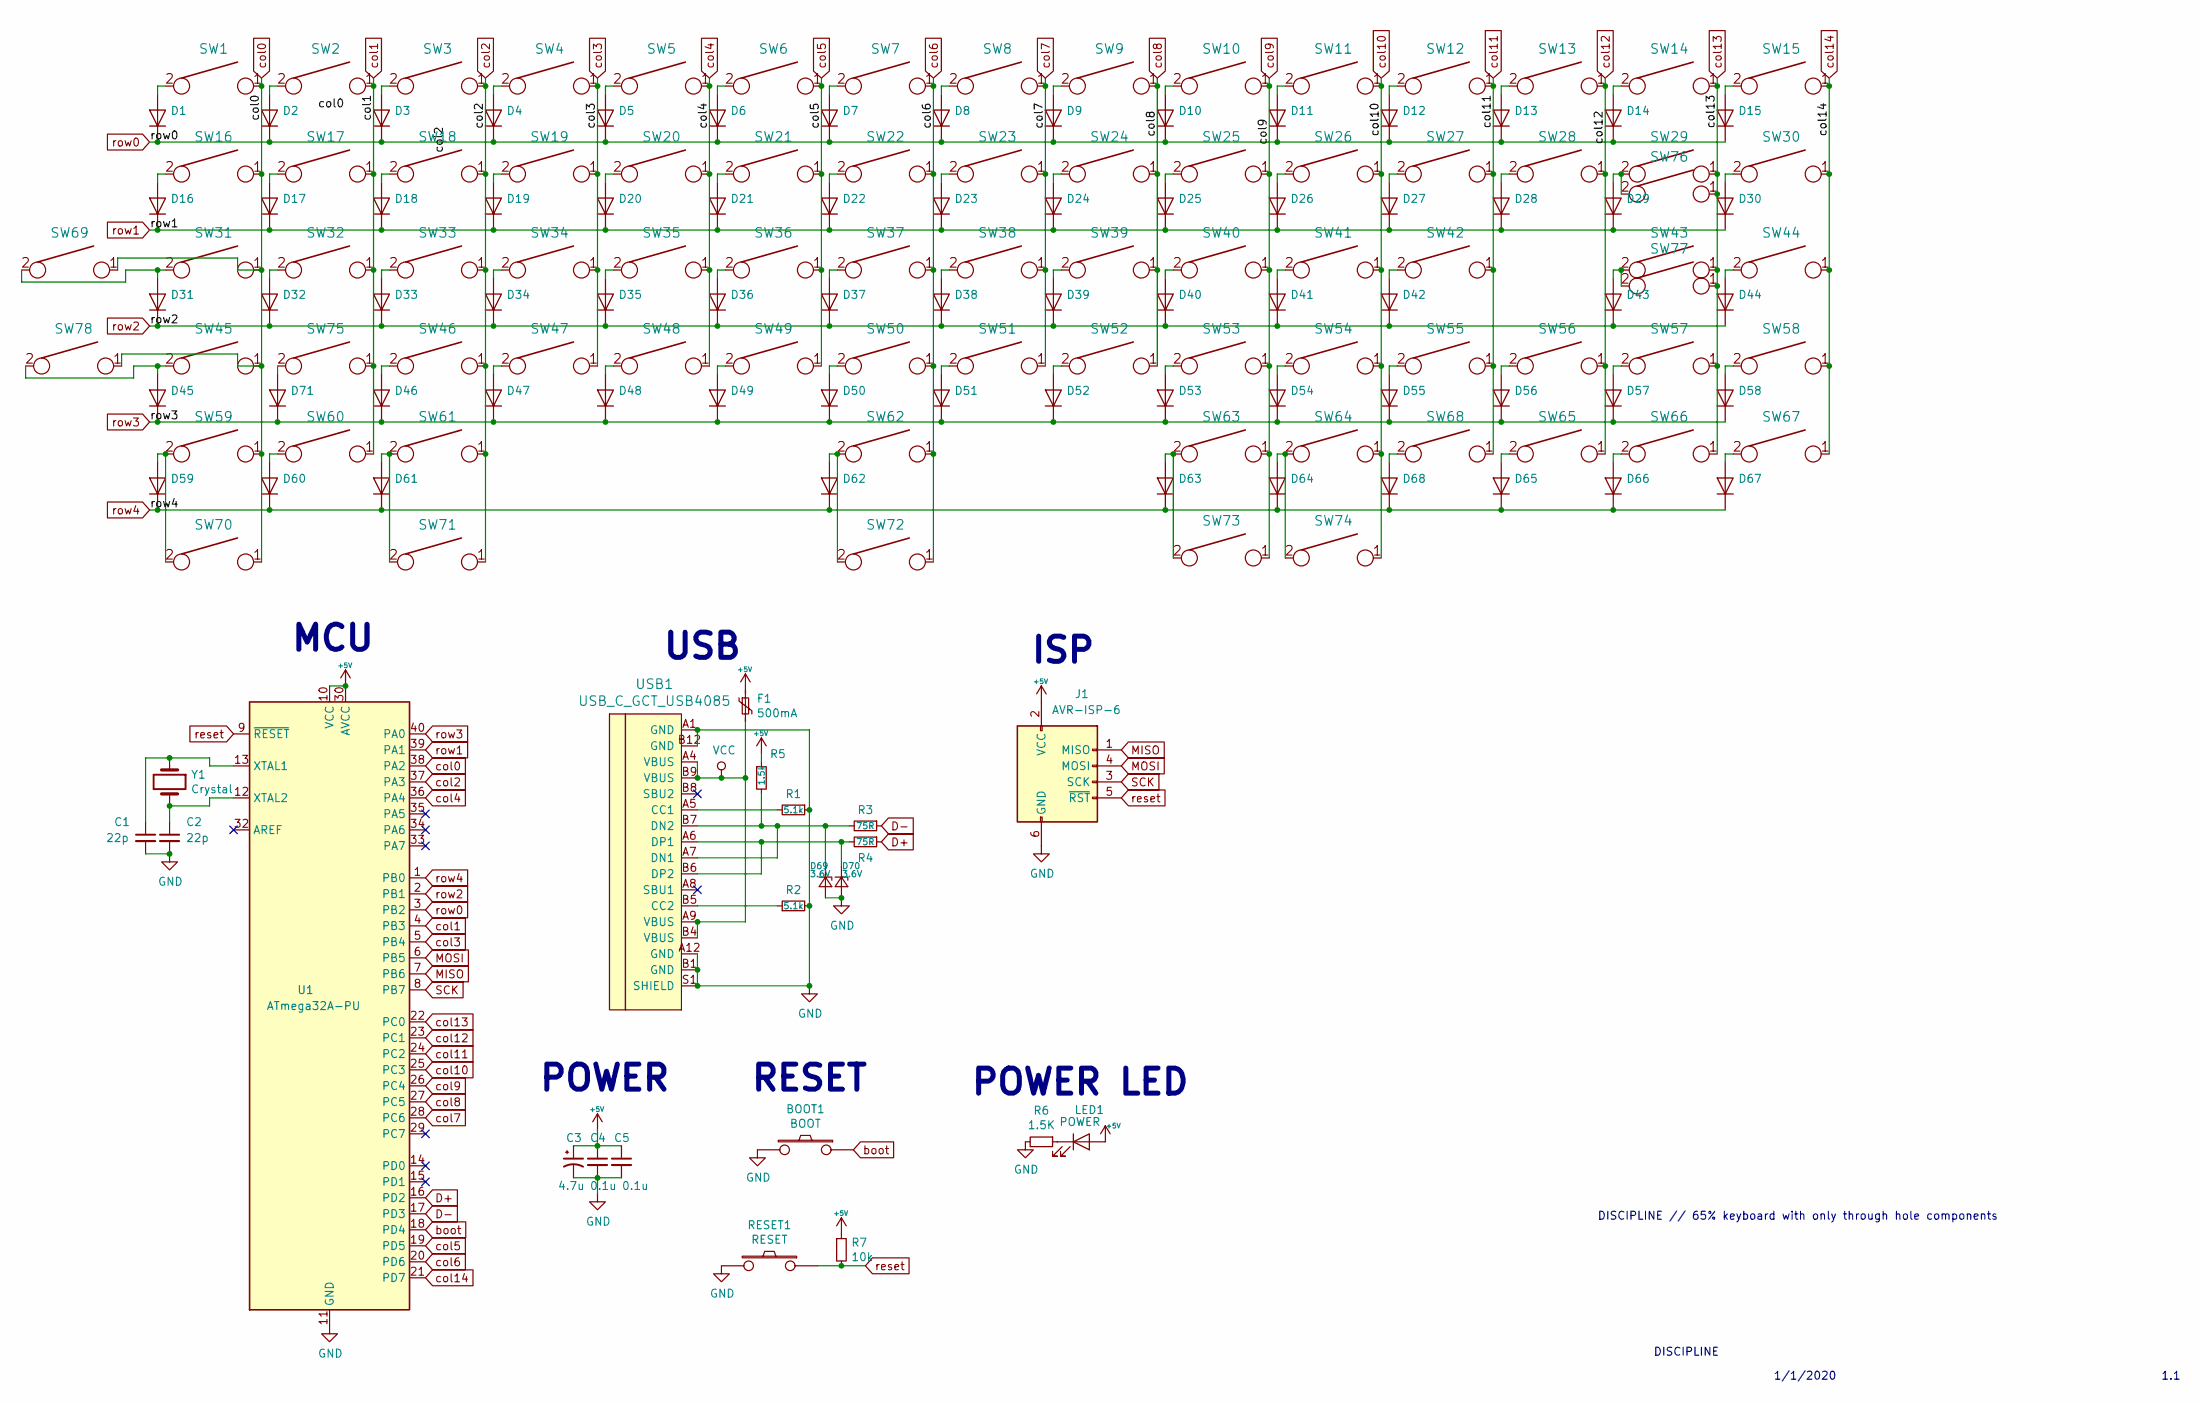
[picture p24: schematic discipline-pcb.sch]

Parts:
BOOT1: BOOT; SW_PUSH_6mm
C1, C2: 22p; C_Disc_D3.0mm_W1.6mm_P2.50mm
C3: 4.7u; CP_Radial_D4.0mm_P1.50mm
C4, C5: 0.1u; C_Disc_D4.3mm_W1.9mm_P5.00mm
D1, D2, D3, D4, D5, D6, D7, D8, D9, D10, D11, D12, D13, D14, D15, D16, D17, D18, D19, D20, D21, D22, D23, D24, D25, D26, D27, D28, D29, D30, D31, D32, D33, D34, D35, D36, D37, D38, D39, D40, D41, D42, D43, D44, D45, D46, D47, D48, D49, D50, D51, D52, D53, D54, D55, D56, D57, D58, D59, D60, D61, D62, D63, D64, D65, D66, D67, D68, D71: D_DO-35_SOD27_P5.08mm_Horizontal
D69, D70: 3.6V; D_DO-35_SOD27_P5.08mm_Horizontal
F1: 500mA; polyfuse_5.1mm
J1: AVR-ISP-6; AVR_ICSP_3x2
LED1: POWER; LED_D3.0mm
R1, R2: 5.1k; R_Axial_DIN0204_L3.6mm_D1.6mm_P5.08mm_Horizontal
R3, R4: 75R; R_Axial_DIN0204_L3.6mm_D1.6mm_P5.08mm_Horizontal
R5: 1.5k; R_Axial_DIN0204_L3.6mm_D1.6mm_P5.08mm_Horizontal
R6: 1.5K; R_Axial_DIN0204_L3.6mm_D1.6mm_P5.08mm_Horizontal
R7: 10k; R_Axial_DIN0204_L3.6mm_D1.6mm_P5.08mm_Horizontal
RESET1: RESET; SW_PUSH_6mm
SW1, SW2, SW3, SW4, SW5, SW6, SW7, SW8, SW9, SW10, SW11, SW12, SW13, SW15, SW17, SW18, SW19, SW20, SW21, SW22, SW23, SW24, SW25, SW26, SW27, SW28, SW30, SW32, SW33, SW34, SW35, SW36, SW37, SW38, SW39, SW40, SW41, SW42, SW44, SW46, SW47, SW48, SW49, SW50, SW51, SW52, SW53, SW54, SW55, SW57, SW58, SW62, SW65, SW66, SW67, SW68, SW72, SW75, SW77: KEYSW; SW_Cherry_MX1A_1.00u_PCB-NOSCREEN
SW14: KEYSW; SW_Cherry_MX1A_2.00u_PCBNOSCREEN
SW16, SW29, SW70, SW71, SW73, SW74: KEYSW; SW_Cherry_MX1A_1.50u_PCBNOSCREEN
SW31, SW56: KEYSW; SW_Cherry_MX1A_1.75u_PCBNOSCREEN
SW43, SW45: KEYSW; SW_Cherry_MX1A_2.25u_PCBNOSCREEN
SW59, SW60, SW61, SW63, SW64, SW69, SW78: KEYSW; SW_Cherry_MX1A_1.25u_PCBNOSCREEN
SW76: KEYSW; SW_Cherry_MX1A_ISOEnter_PCB_ReversedStabilizer
U1: ATmega32A-PU; DIP-40_W15.24mm
USB1: USB_C_GCT_USB4085
Y1: Crystal; Crystal_HC49-4H_Vertical

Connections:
+5V: C3.1, C4.1, C5.1, F1.1, J1.2 (VCC), LED1.2 (A), R5.1, R7.1, U1.10 (VCC), U1.30 (AVCC)
D+: R4.1, U1.16 (PD2)
D-: R3.1, U1.17 (PD3)
GND: BOOT1.1, C1.2, C2.2, C3.2, C4.2, C5.2, D69.2 (A), D70.2 (A), J1.6 (GND), R1.1, R2.2, R6.2, RESET1.1, U1.11 (GND), U1.31 (GND), USB1.A1 (GND), USB1.A12 (GND), USB1.B1 (GND), USB1.B12 (GND), USB1.S1 (SHIELD)
MISO: J1.1 (MISO), U1.7 (PB6)
MOSI: J1.4 (MOSI), U1.6 (PB5)
unnamed: C1.1, U1.13 (XTAL1), Y1.1
unnamed: C2.1, U1.12 (XTAL2), Y1.2
unnamed: D1.2 (A), SW1.2
unnamed: D2.2 (A), SW2.2
unnamed: D3.2 (A), SW3.2
unnamed: D4.2 (A), SW4.2
unnamed: D5.2 (A), SW5.2
unnamed: D6.2 (A), SW6.2
unnamed: D7.2 (A), SW7.2
unnamed: D8.2 (A), SW8.2
unnamed: D9.2 (A), SW9.2
unnamed: D10.2 (A), SW10.2
unnamed: D11.2 (A), SW11.2
unnamed: D12.2 (A), SW12.2
unnamed: D13.2 (A), SW13.2
unnamed: D14.2 (A), SW14.2
unnamed: D15.2 (A), SW15.2
unnamed: D16.2 (A), SW16.2
unnamed: D17.2 (A), SW17.2
unnamed: D18.2 (A), SW18.2
unnamed: D19.2 (A), SW19.2
unnamed: D20.2 (A), SW20.2
unnamed: D21.2 (A), SW21.2
unnamed: D22.2 (A), SW22.2
unnamed: D23.2 (A), SW23.2
unnamed: D24.2 (A), SW24.2
unnamed: D25.2 (A), SW25.2
unnamed: D26.2 (A), SW26.2
unnamed: D27.2 (A), SW27.2
unnamed: D28.2 (A), SW28.2
unnamed: D29.2 (A), SW29.2, SW76.2
unnamed: D30.2 (A), SW30.2
unnamed: D31.2 (A), SW31.2, SW69.2
unnamed: D32.2 (A), SW32.2
unnamed: D33.2 (A), SW33.2
unnamed: D34.2 (A), SW34.2
unnamed: D35.2 (A), SW35.2
unnamed: D36.2 (A), SW36.2
unnamed: D37.2 (A), SW37.2
unnamed: D38.2 (A), SW38.2
unnamed: D39.2 (A), SW39.2
unnamed: D40.2 (A), SW40.2
unnamed: D41.2 (A), SW41.2
unnamed: D42.2 (A), SW42.2
unnamed: D43.2 (A), SW43.2, SW77.2
unnamed: D44.2 (A), SW44.2
unnamed: D45.2 (A), SW45.2, SW78.2
unnamed: D46.2 (A), SW46.2
unnamed: D47.2 (A), SW47.2
unnamed: D48.2 (A), SW48.2
unnamed: D49.2 (A), SW49.2
unnamed: D50.2 (A), SW50.2
unnamed: D51.2 (A), SW51.2
unnamed: D52.2 (A), SW52.2
unnamed: D53.2 (A), SW53.2
unnamed: D54.2 (A), SW54.2
unnamed: D55.2 (A), SW55.2
unnamed: D56.2 (A), SW56.2
unnamed: D57.2 (A), SW57.2
unnamed: D58.2 (A), SW58.2
unnamed: D59.2 (A), SW59.2, SW70.2
unnamed: D60.2 (A), SW60.2
unnamed: D61.2 (A), SW61.2, SW71.2
unnamed: D62.2 (A), SW62.2, SW72.2
unnamed: D63.2 (A), SW63.2, SW73.2
unnamed: D64.2 (A), SW64.2, SW74.2
unnamed: D65.2 (A), SW65.2
unnamed: D66.2 (A), SW66.2
unnamed: D67.2 (A), SW67.2
unnamed: D68.2 (A), SW68.2
unnamed: D69.1 (K), R3.2, R5.2, USB1.A7 (DN1), USB1.B7 (DN2)
unnamed: D70.1 (K), R4.2, USB1.A6 (DP1), USB1.B6 (DP2)
unnamed: D71.2 (A), SW75.2
unnamed: LED1.1 (K), R6.1
unnamed: R1.2, USB1.A5 (CC1)
unnamed: R2.1, USB1.B5 (CC2)
SCK: J1.3 (SCK), U1.8 (PB7)
VCC: F1.2, USB1.A4 (VBUS), USB1.A9 (VBUS), USB1.B4 (VBUS), USB1.B9 (VBUS)
boot: BOOT1.2, U1.18 (PD4)
col0: SW1.1, SW16.1, SW31.1, SW45.1, SW59.1, SW69.1, SW70.1, SW78.1, U1.38 (PA2)
col1: SW2.1, SW17.1, SW32.1, SW60.1, SW75.1, U1.4 (PB3)
col2: SW3.1, SW18.1, SW33.1, SW46.1, SW61.1, SW71.1, U1.37 (PA3)
col3: SW4.1, SW19.1, SW34.1, SW47.1, U1.5 (PB4)
col4: SW5.1, SW20.1, SW35.1, SW48.1, U1.36 (PA4)
col5: SW6.1, SW21.1, SW36.1, SW49.1, U1.19 (PD5)
col6: SW7.1, SW22.1, SW37.1, SW50.1, SW62.1, SW72.1, U1.20 (PD6)
col7: SW8.1, SW23.1, SW38.1, SW51.1, U1.28 (PC6)
col8: SW9.1, SW24.1, SW39.1, SW52.1, U1.27 (PC5)
col9: SW10.1, SW25.1, SW40.1, SW53.1, SW63.1, SW73.1, U1.26 (PC4)
col10: SW11.1, SW26.1, SW41.1, SW54.1, SW64.1, SW74.1, U1.25 (PC3)
col11: SW12.1, SW27.1, SW42.1, SW55.1, SW68.1, U1.24 (PC2)
col12: SW13.1, SW28.1, SW56.1, SW65.1, U1.23 (PC1)
col13: SW14.1, SW29.1, SW43.1, SW57.1, SW66.1, SW76.1, SW77.1, U1.22 (PC0)
col14: SW15.1, SW30.1, SW44.1, SW58.1, SW67.1, U1.21 (PD7)
reset: J1.5 (~RST), R7.2, RESET1.2, U1.9 (~RESET)
row0: D1.1 (K), D2.1 (K), D3.1 (K), D4.1 (K), D5.1 (K), D6.1 (K), D7.1 (K), D8.1 (K), D9.1 (K), D10.1 (K), D11.1 (K), D12.1 (K), D13.1 (K), D14.1 (K), D15.1 (K), U1.3 (PB2)
row1: D16.1 (K), D17.1 (K), D18.1 (K), D19.1 (K), D20.1 (K), D21.1 (K), D22.1 (K), D23.1 (K), D24.1 (K), D25.1 (K), D26.1 (K), D27.1 (K), D28.1 (K), D29.1 (K), D30.1 (K), U1.39 (PA1)
row2: D31.1 (K), D32.1 (K), D33.1 (K), D34.1 (K), D35.1 (K), D36.1 (K), D37.1 (K), D38.1 (K), D39.1 (K), D40.1 (K), D41.1 (K), D42.1 (K), D43.1 (K), D44.1 (K), U1.2 (PB1)
row3: D45.1 (K), D46.1 (K), D47.1 (K), D48.1 (K), D49.1 (K), D50.1 (K), D51.1 (K), D52.1 (K), D53.1 (K), D54.1 (K), D55.1 (K), D56.1 (K), D57.1 (K), D58.1 (K), D71.1 (K), U1.40 (PA0)
row4: D59.1 (K), D60.1 (K), D61.1 (K), D62.1 (K), D63.1 (K), D64.1 (K), D65.1 (K), D66.1 (K), D67.1 (K), D68.1 (K), U1.1 (PB0)

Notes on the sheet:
DISCIPLINE // 65% keyboard with only through hole components
1/1/2020
DISCIPLINE
1.1
MCU
USB
ISP
POWER
RESET
POWER LED

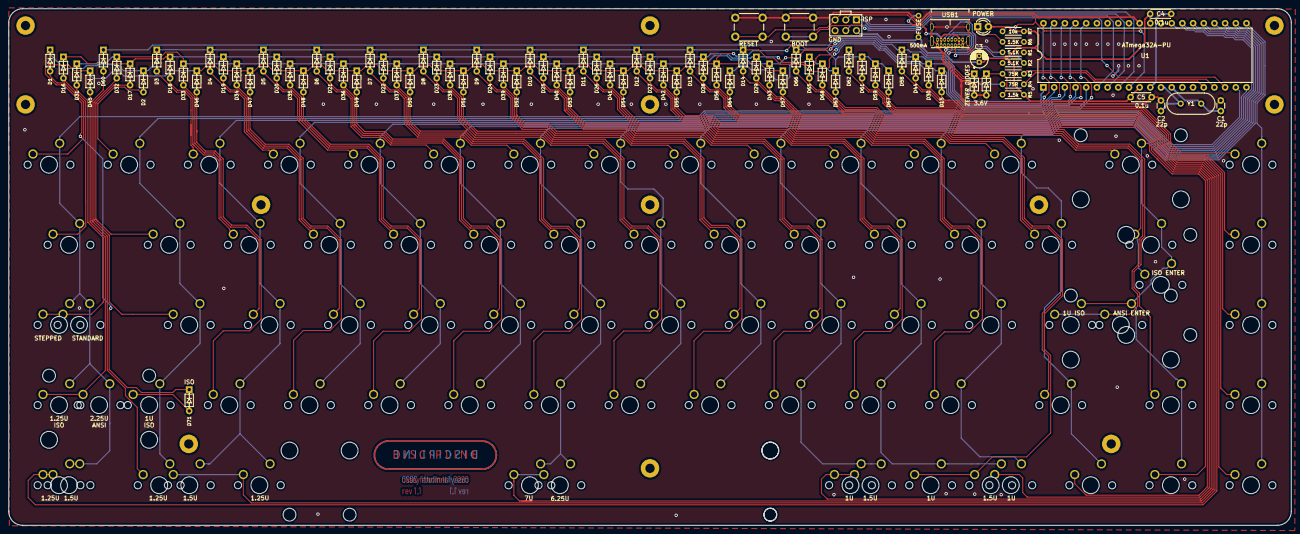
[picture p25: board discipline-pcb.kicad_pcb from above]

Board: 2 copper layers, 304.9 x 122.8 mm, 170 parts (0 on the bottom side), 106 nets.

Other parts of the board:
ST72: 7U; MX-7U-Stabilizer

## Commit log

2019-07-31 update screenprint and gerbers
    [discipline-pcb-B.Cu.gbr, discipline-pcb-B.Mask.gbr, discipline-pcb-B.Paste.gbr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]
2019-08-04 clean up symbol labels
    [discipline-pcb.sch]
2019-08-06 update ic socket 3d model
    [discipline-pcb.kicad_pcb]
2019-08-12 fix rctl switch not clipping in
    [discipline-pcb.kicad_pcb]
2019-08-12 fix off center screenprint
    [discipline-pcb.kicad_pcb]
2019-08-12 update gerbers
    [discipline-pcb-B.Cu.gbr, discipline-pcb-B.Mask.gbr, discipline-pcb-B.Paste.gbr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]
2019-08-12 fix off center screenprint and update gerbers
    [discipline-pcb-B.Cu.gbr, discipline-pcb-B.Mask.gbr, discipline-pcb-B.Paste.gbr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]
2019-08-15 change fuse value
    change fuse value from 100mA to 500mA. 100mA is fine for this use, but 500mA is USB 2.0 standard
    [discipline-pcb.kicad_pcb, discipline-pcb.sch]
2019-08-17 Update discipline-pcb.kicad_pcb-bak
2019-09-21 update gerber
    [discipline-pcb-B.Cu.gbr, discipline-pcb-B.Mask.gbr, discipline-pcb-B.Paste.gbr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]
2019-10-10 Create discipline-pcb.sch-bak
2019-10-10 Update discipline-pcb.sch-bak
2019-10-11 Revert "Update discipline-pcb.sch-bak"
    This reverts commit 60fd8acc146e0f24326ca4f8e676ff7e12e92cee.
2019-10-11 Revert "Update discipline-pcb.sch"
    This reverts commit 3febe6e3f5ee2dfceb20178832481c5907b2c946.
    [discipline-pcb.sch]
2019-10-11 Revert "Create discipline-pcb.sch-bak"
    This reverts commit 3dc7e60d808c34b2b86821be701f68a6a7846385.
2019-10-11 Revert "Update discipline-pcb.sch"
    This reverts commit a72fcd6089ef7a7854f28251b3b3dd299a3c70af.
    [discipline-pcb.sch]
2019-10-11 Revert "Update discipline-pcb.pro"
    This reverts commit 51cc2ebde8eba7a8e5a88cedf6e40d973d857545.
2019-10-11 Revert "Update discipline-pcb.kicad_pcb-bak"
    This reverts commit 6f9d74d532aa9e57c588e09e20049bdd6adf1f67.
2019-10-11 Revert "Update discipline-pcb.kicad_pcb"
    This reverts commit 5b5a9406b507a9cf9a6000bfc02bb23341a56901.
    [discipline-pcb.kicad_pcb]
2019-10-11 Revert "Update discipline-pcb-cache.lib"
    This reverts commit 5b9b895ae407158b4ad500140b0865a0e21e73d9.
2019-10-12 add schematic symbols for alternate switches so netlist updates properly
    [discipline-pcb.sch]
2020-02-12 Add case .dxf files
    [discipline-bottom.dxf, discipline-closed-layer.dxf, discipline-foot-1.dxf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]
2020-04-20 fix scaling
    [discipline-bottom.dxf, discipline-closed-layer.dxf, discipline-foot-1.dxf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]
2020-04-28 add case photo
2020-06-26 Update to V2, add ISO support, update license
    [acrylic-guard.dxf, discipline-bottom.dxf, discipline-closed-layer.dxf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]
